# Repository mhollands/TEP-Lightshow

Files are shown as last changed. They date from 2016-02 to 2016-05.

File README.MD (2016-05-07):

This is the 2016 redesign of the Tau Epsilon Phi, Xi Chapter (MIT) light show. The aim is to have 32 individually addressable 20A wall outlets (on the ceiling). Using the DMX512 protocol, we will be able to turn on, turn off or dim any of the 32 outlets. The DMX signal will come from a PC. The main use of this is to flash the lights in accordance with the current music, via a frequency analysis of the sound, however it will likely also be used for controlling the general lighting in the room, as well as whatever we dream up.

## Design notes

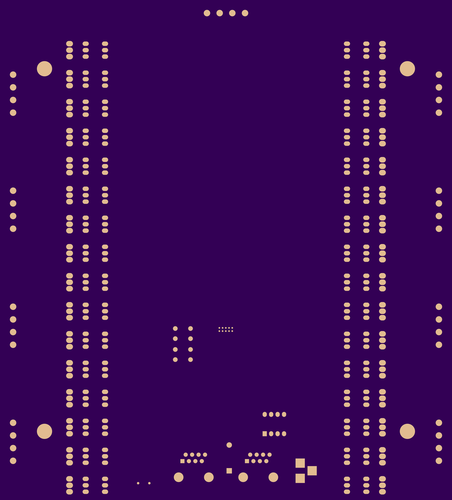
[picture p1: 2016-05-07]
Gerber/Renders/bottommask.png

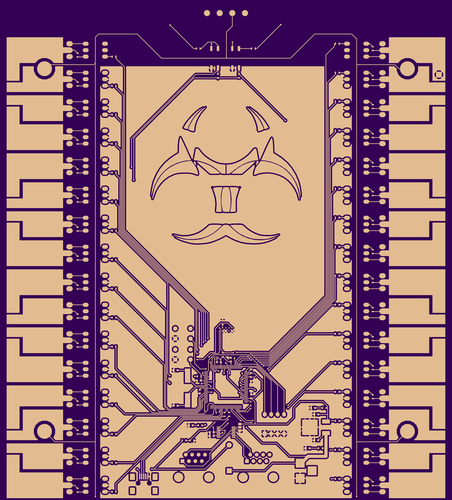
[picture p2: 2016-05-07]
Gerber/Renders/topcu.png

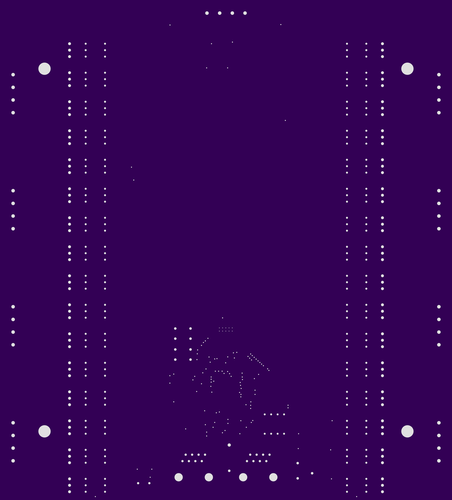
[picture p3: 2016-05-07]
Gerber/Renders/drills.png

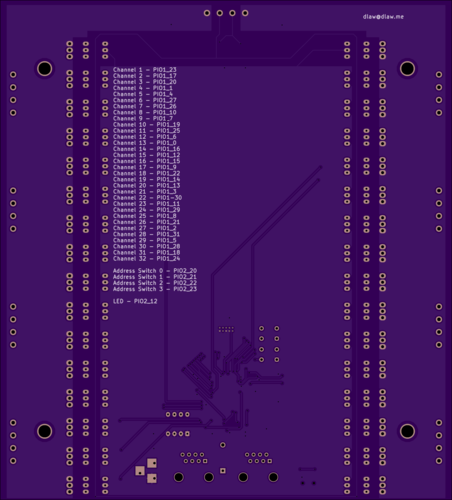
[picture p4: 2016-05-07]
Gerber/Renders/bottom.png

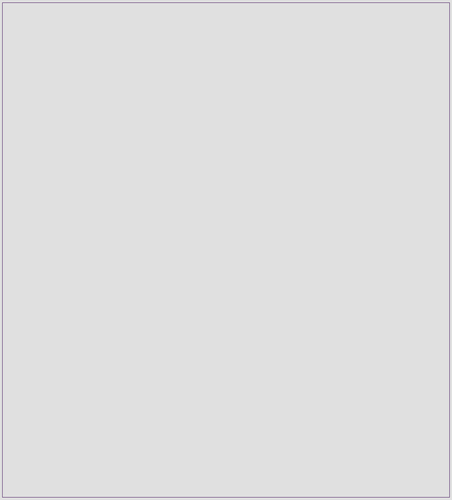
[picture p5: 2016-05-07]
Gerber/Renders/outline.png

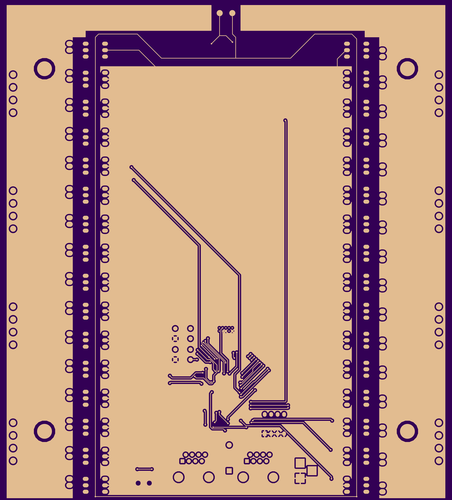
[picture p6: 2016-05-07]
Gerber/Renders/bottomcu.png

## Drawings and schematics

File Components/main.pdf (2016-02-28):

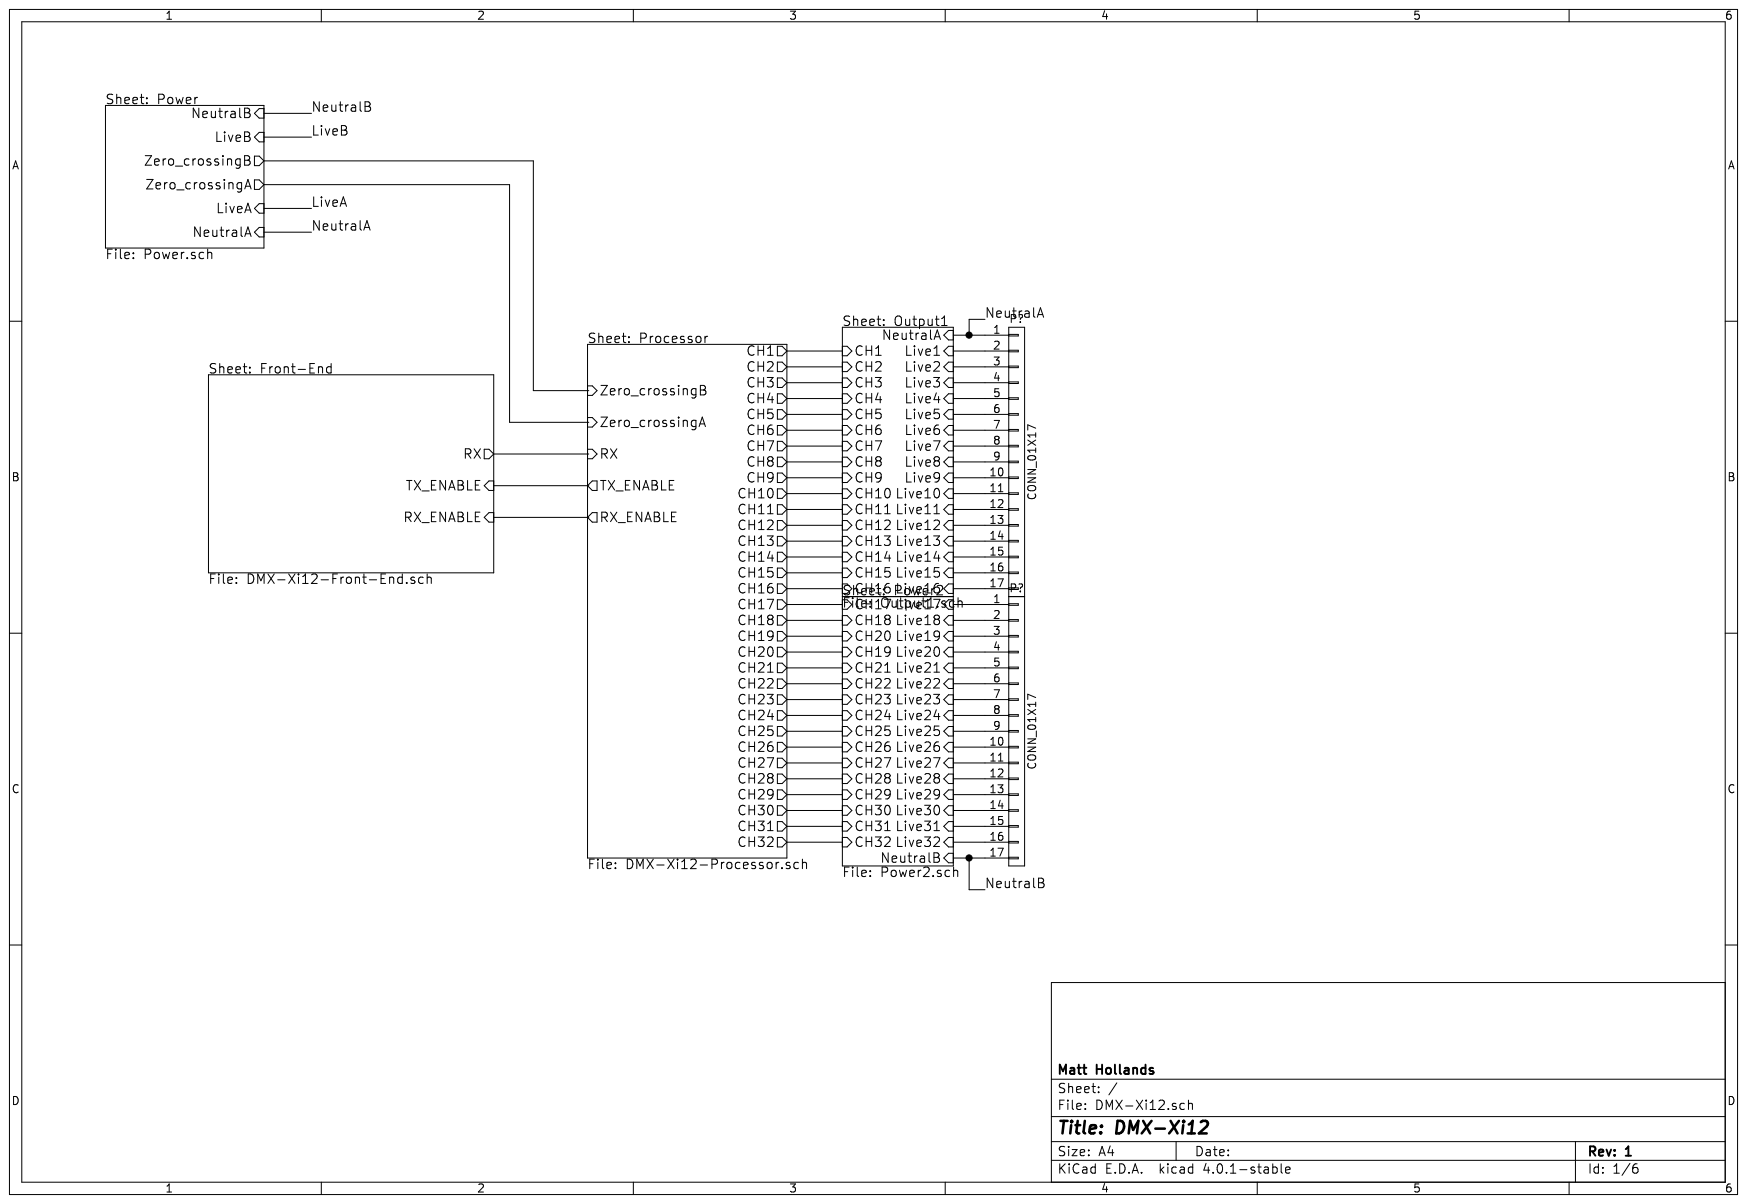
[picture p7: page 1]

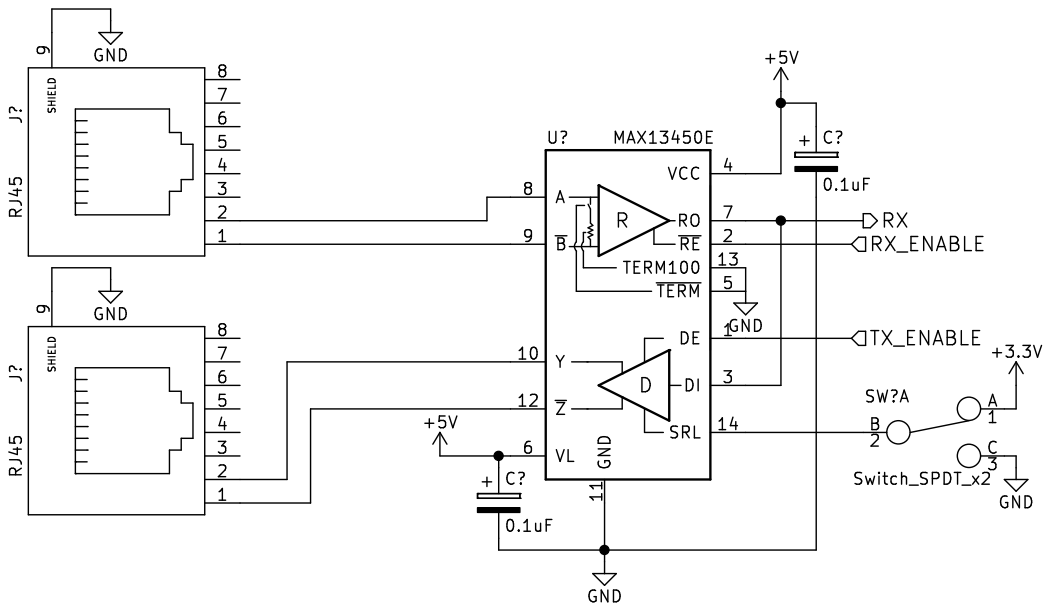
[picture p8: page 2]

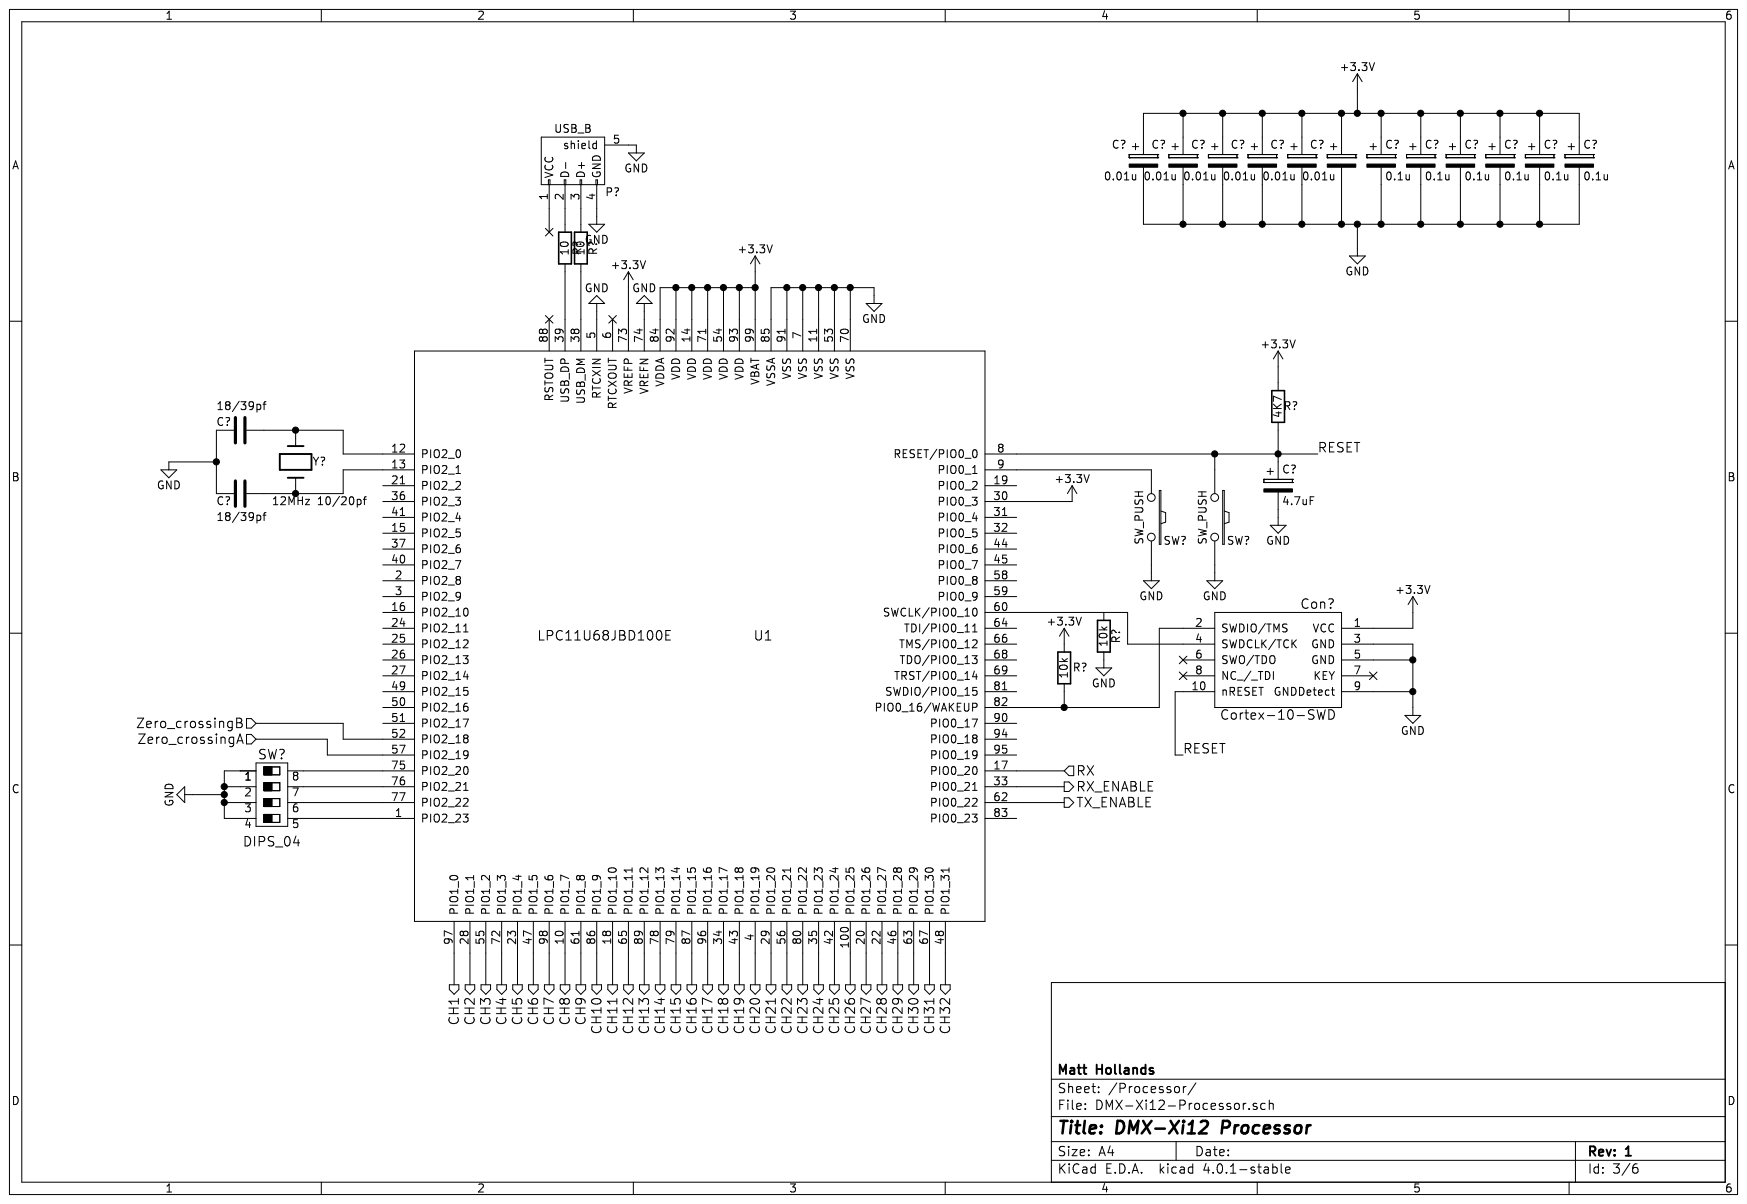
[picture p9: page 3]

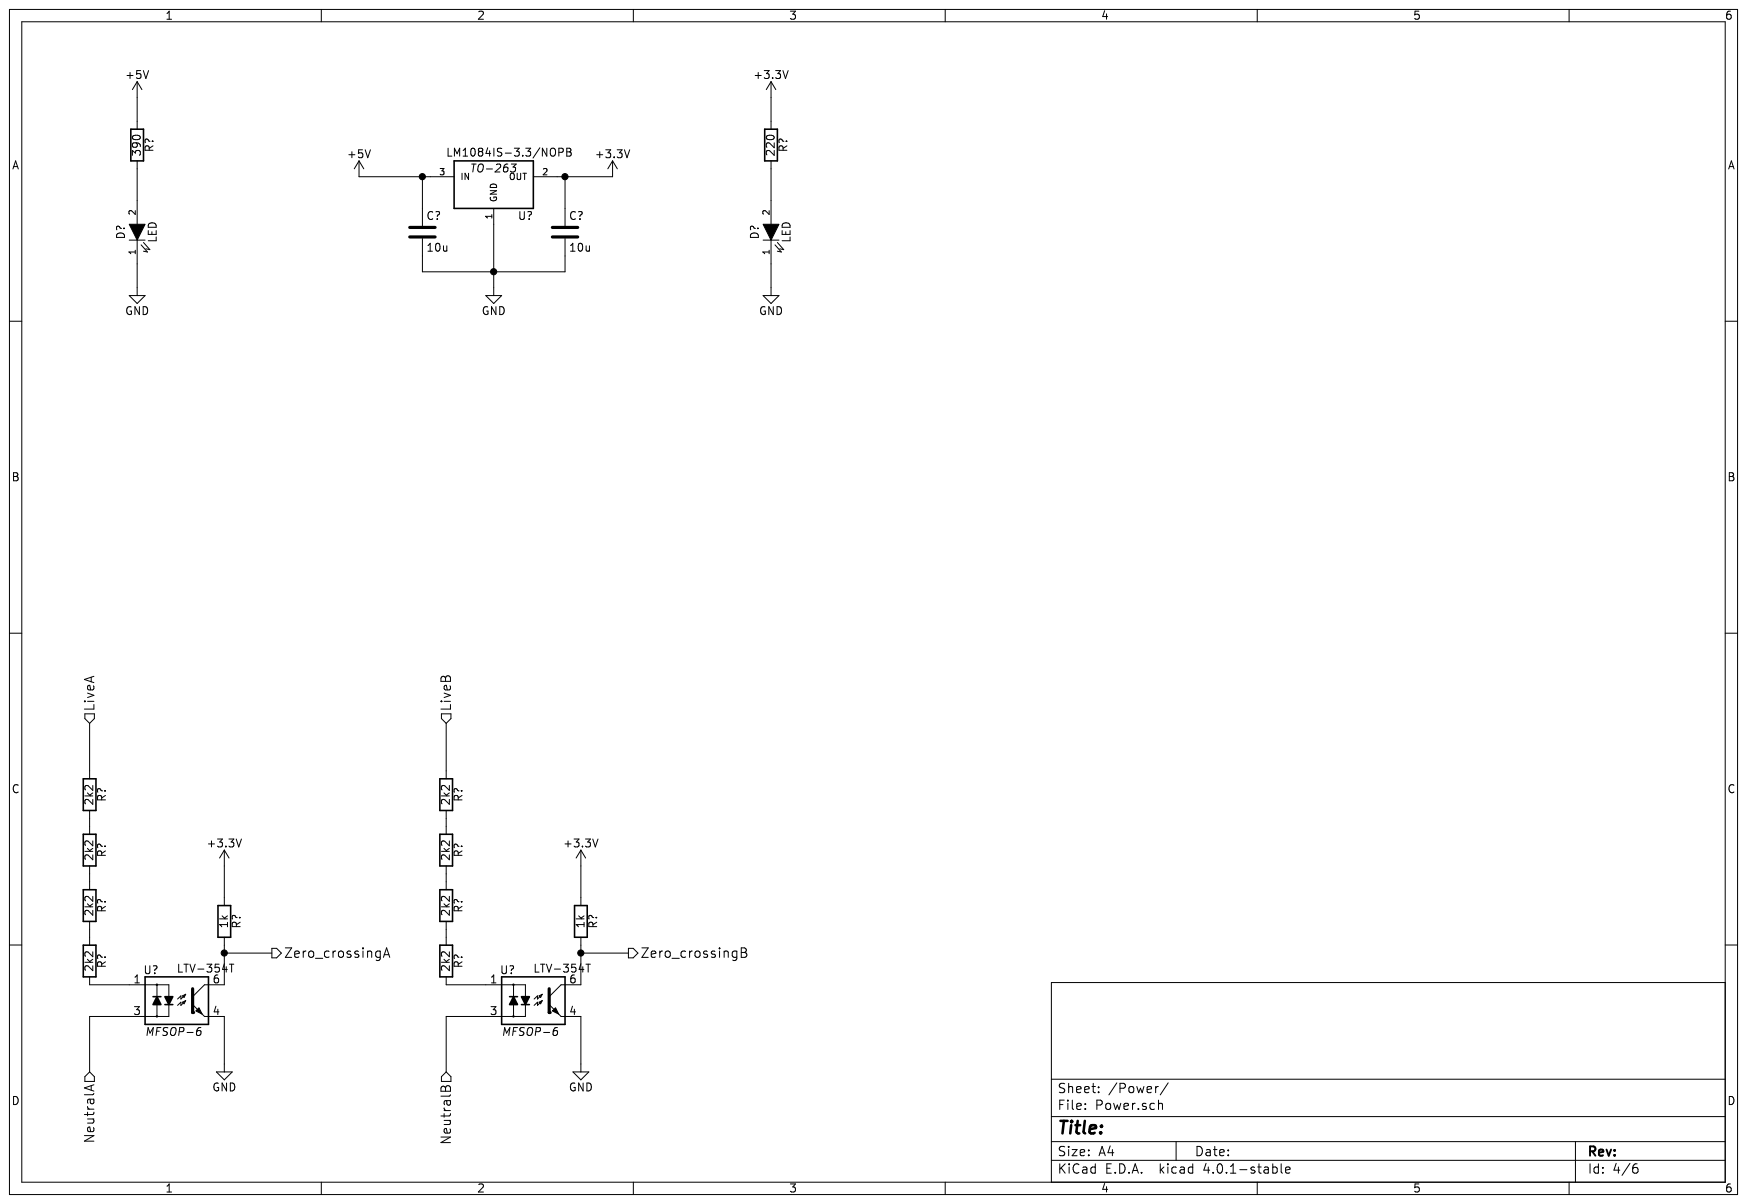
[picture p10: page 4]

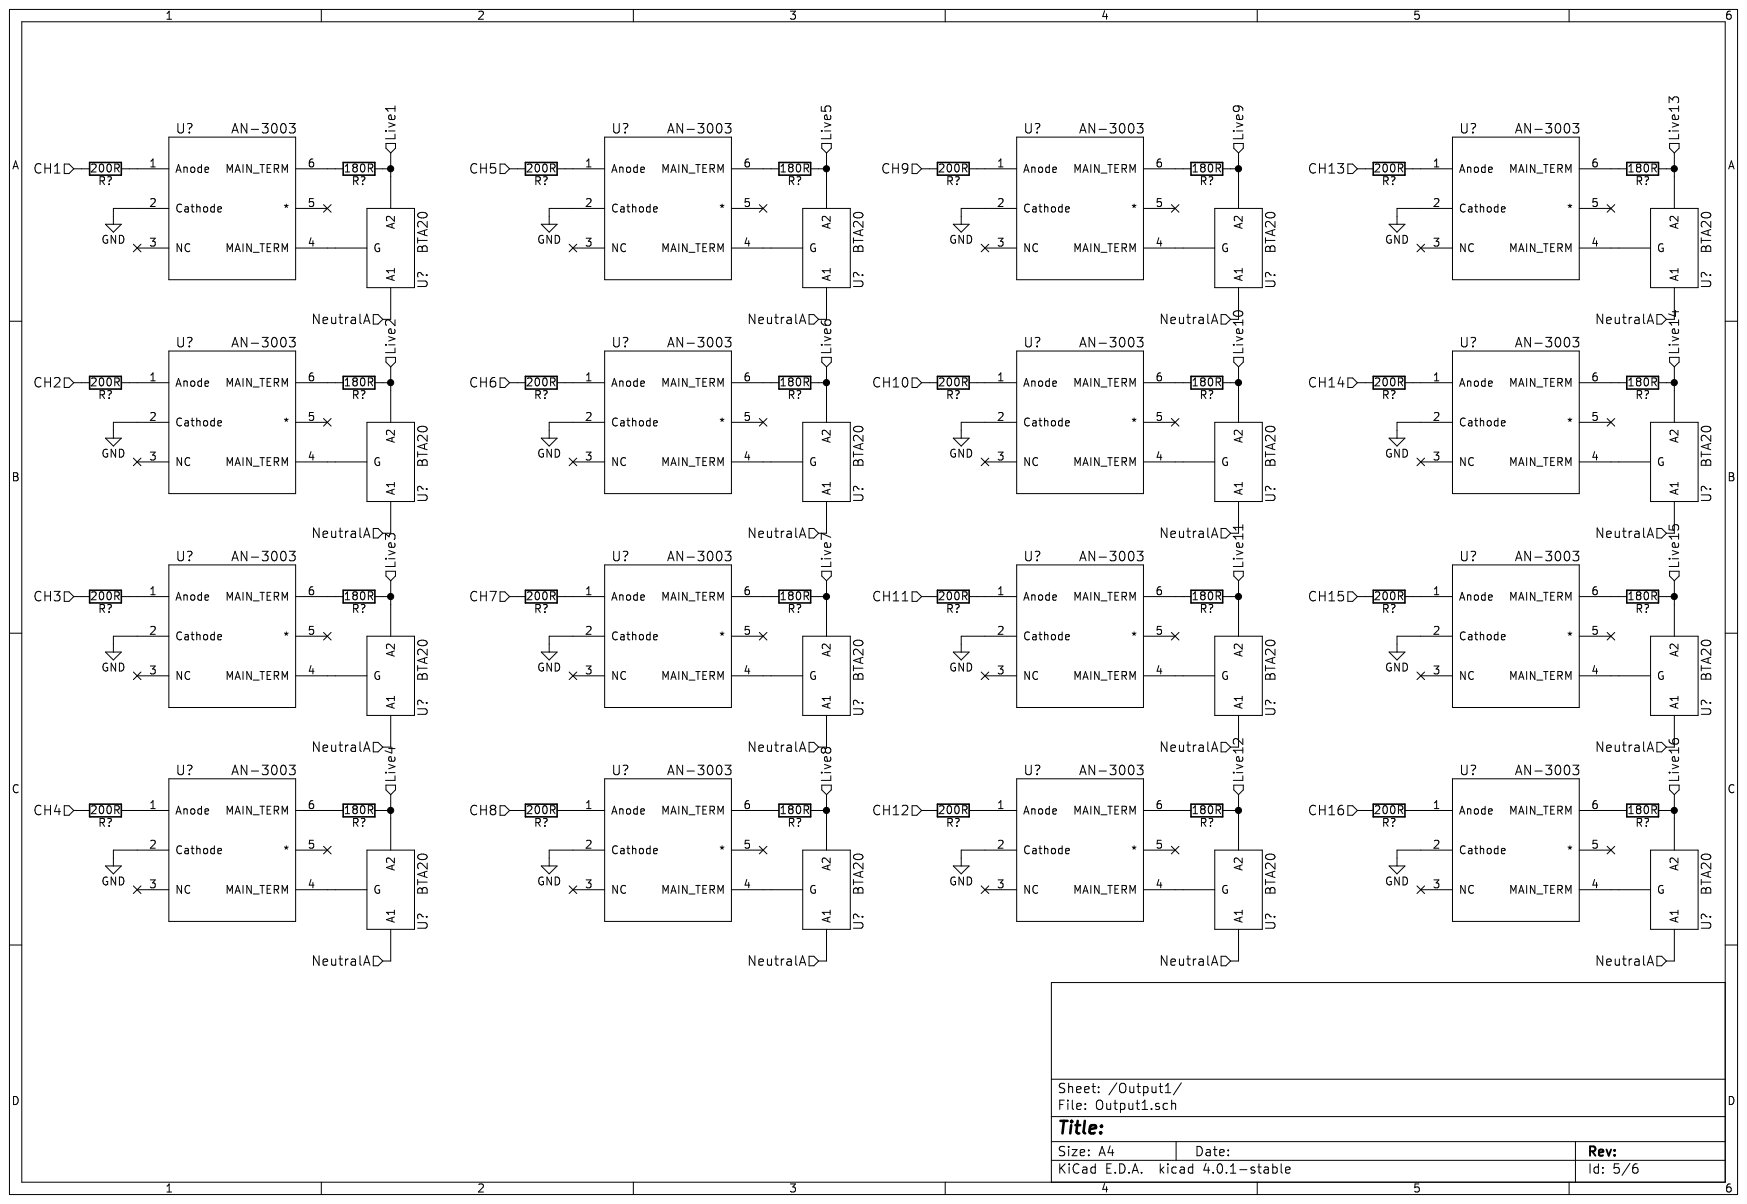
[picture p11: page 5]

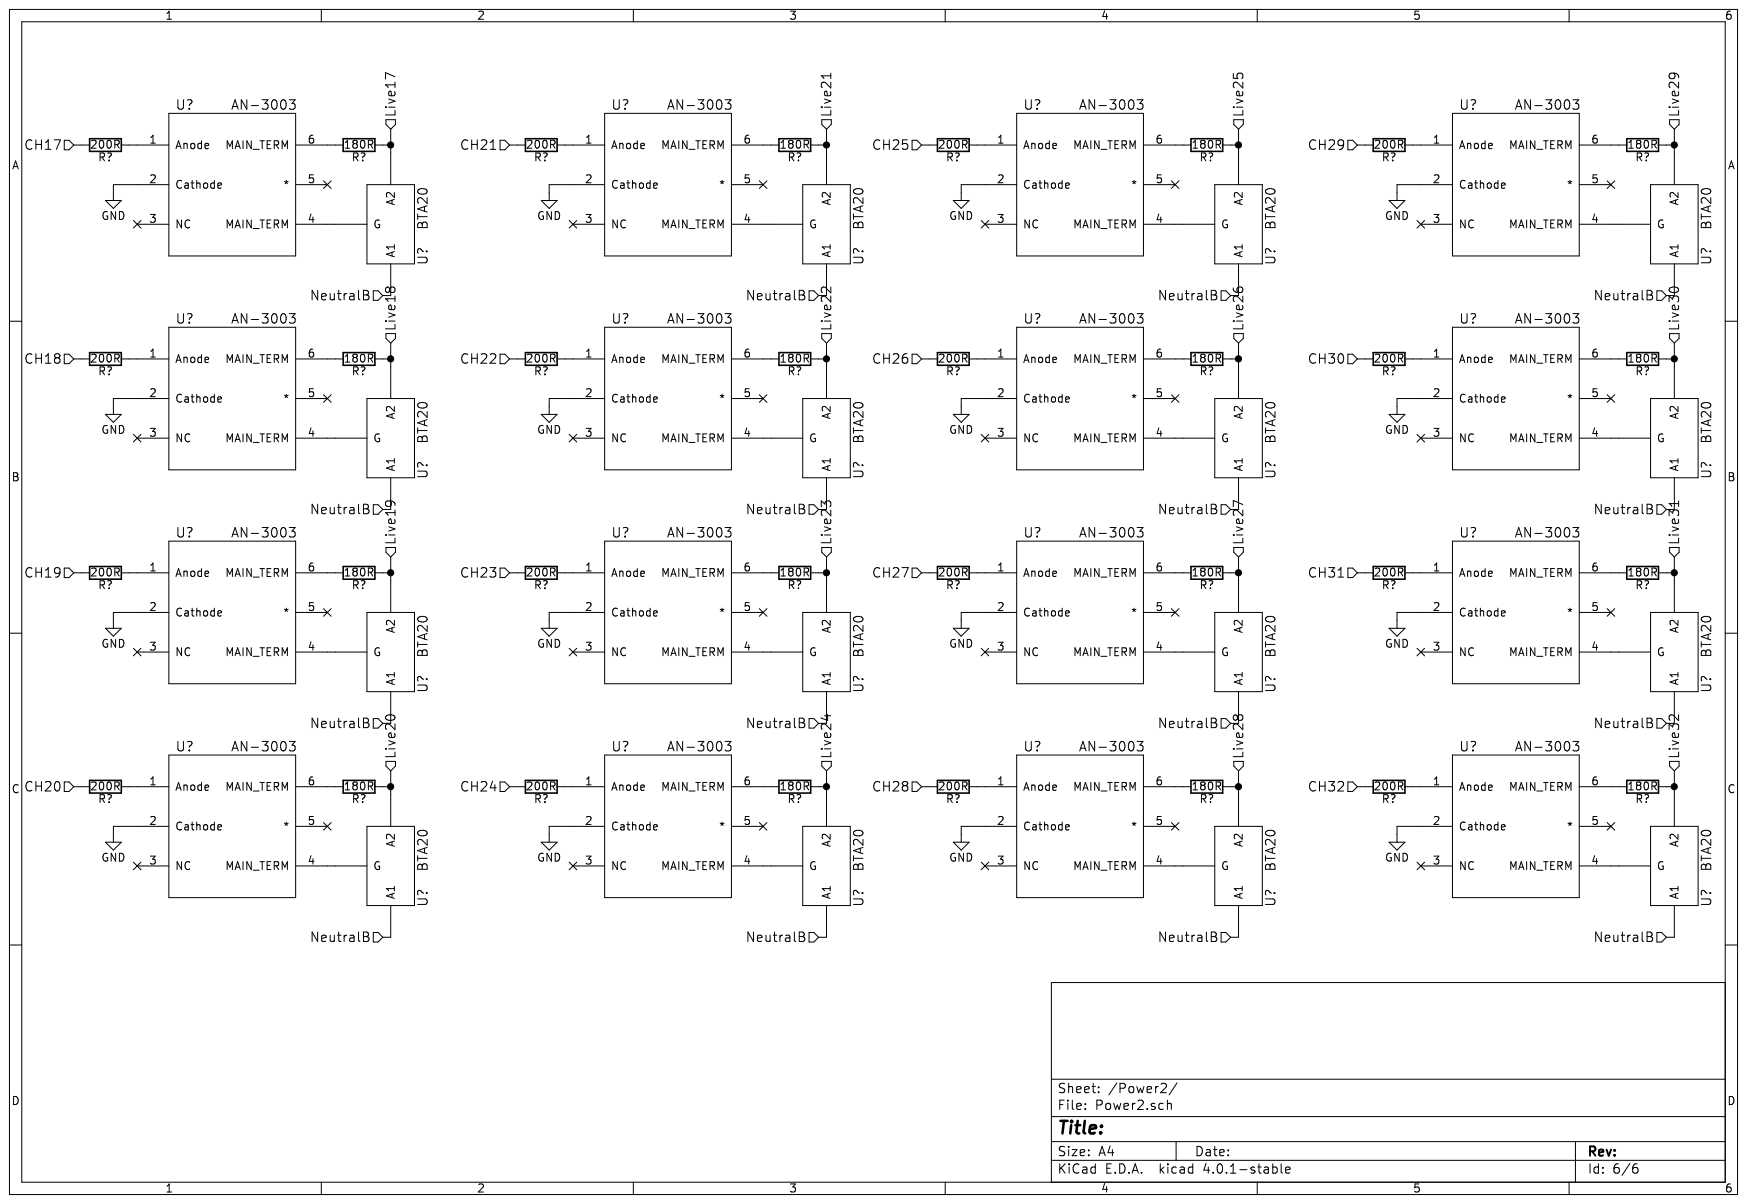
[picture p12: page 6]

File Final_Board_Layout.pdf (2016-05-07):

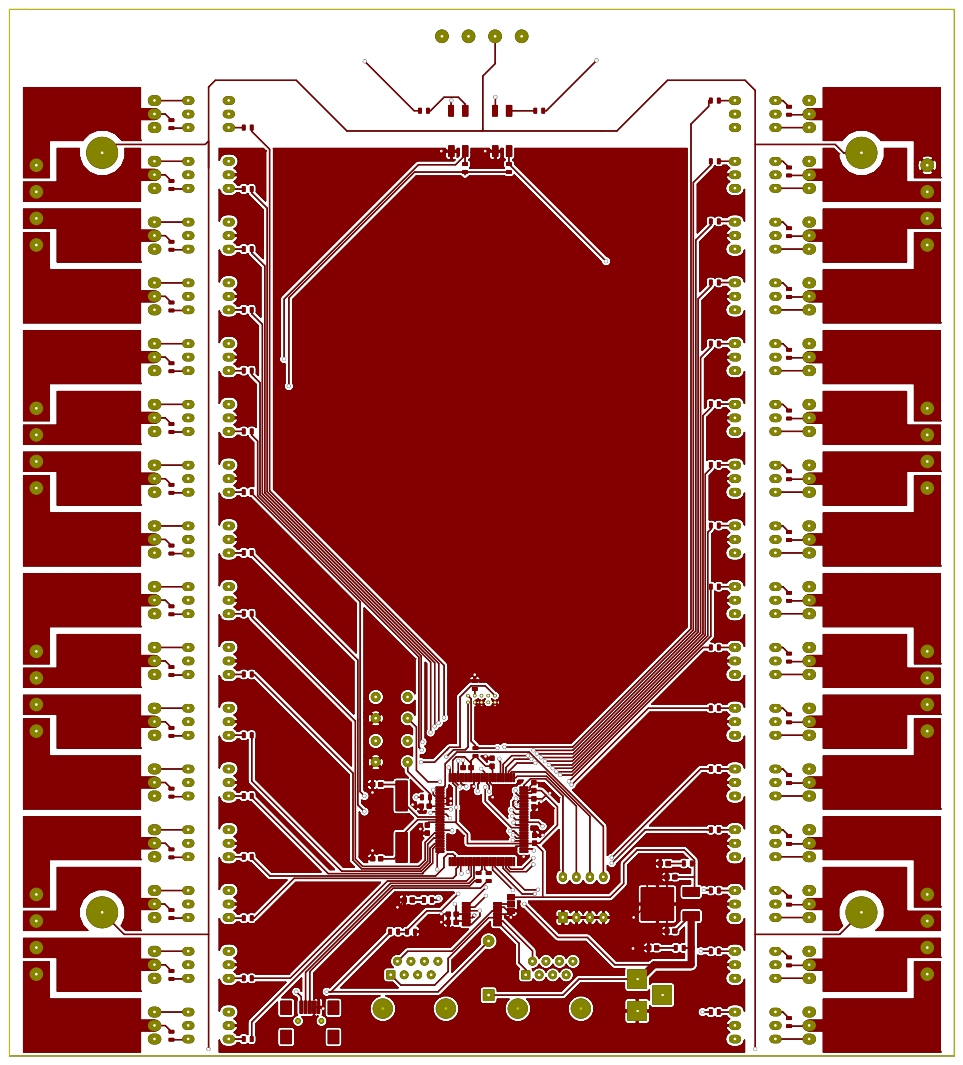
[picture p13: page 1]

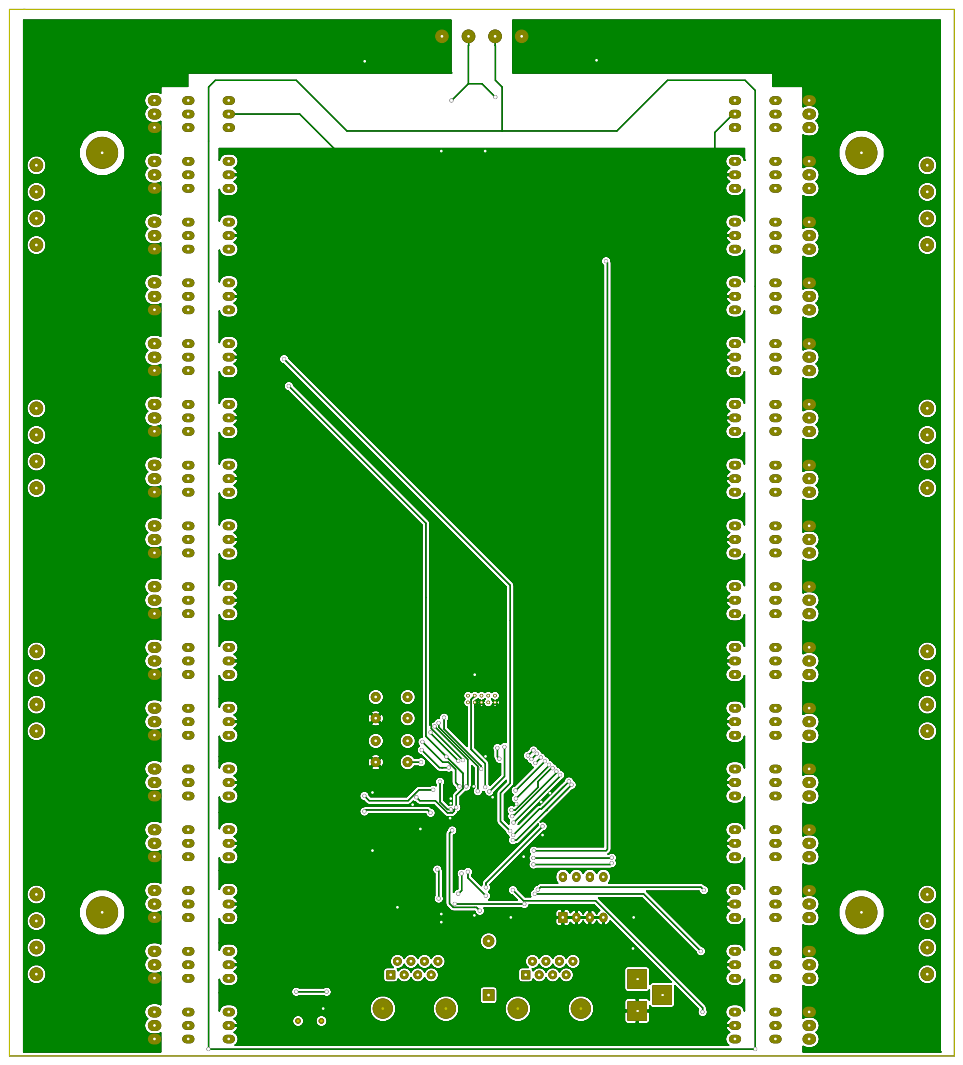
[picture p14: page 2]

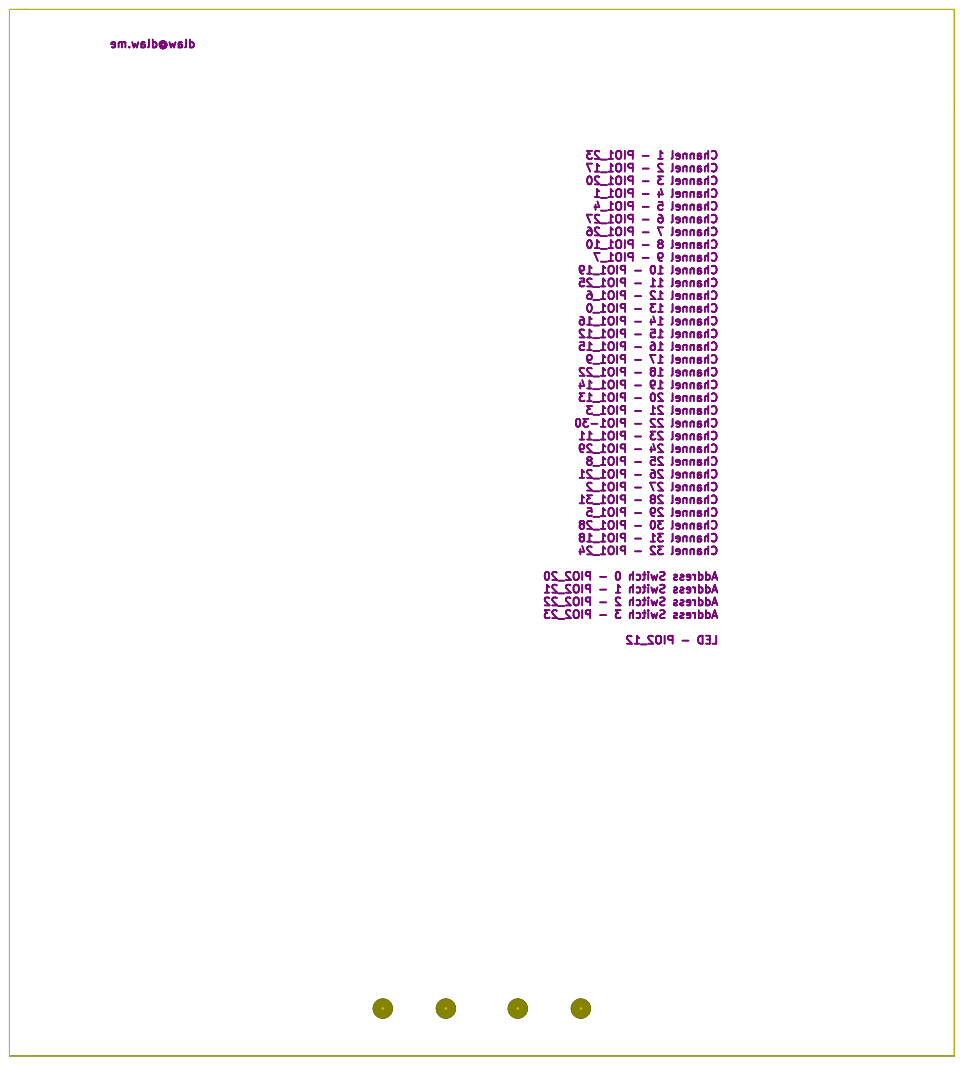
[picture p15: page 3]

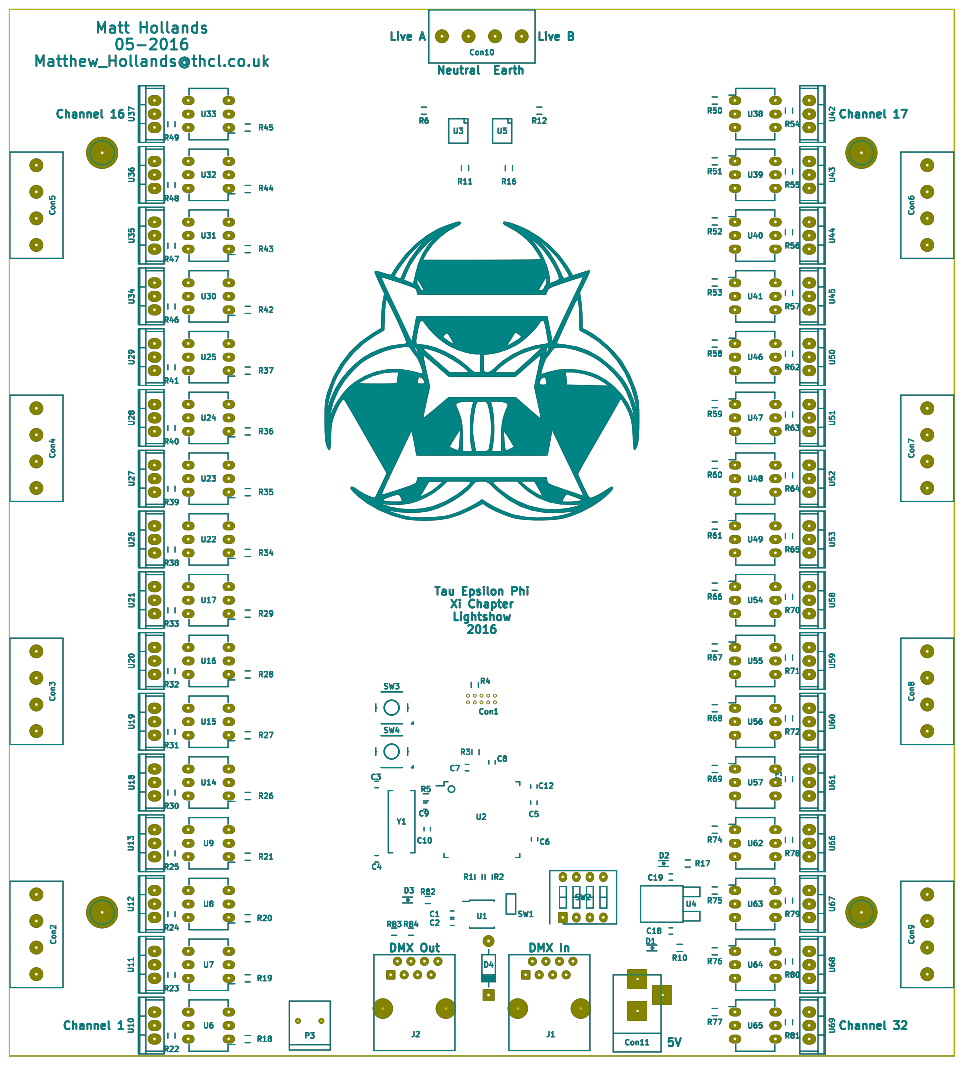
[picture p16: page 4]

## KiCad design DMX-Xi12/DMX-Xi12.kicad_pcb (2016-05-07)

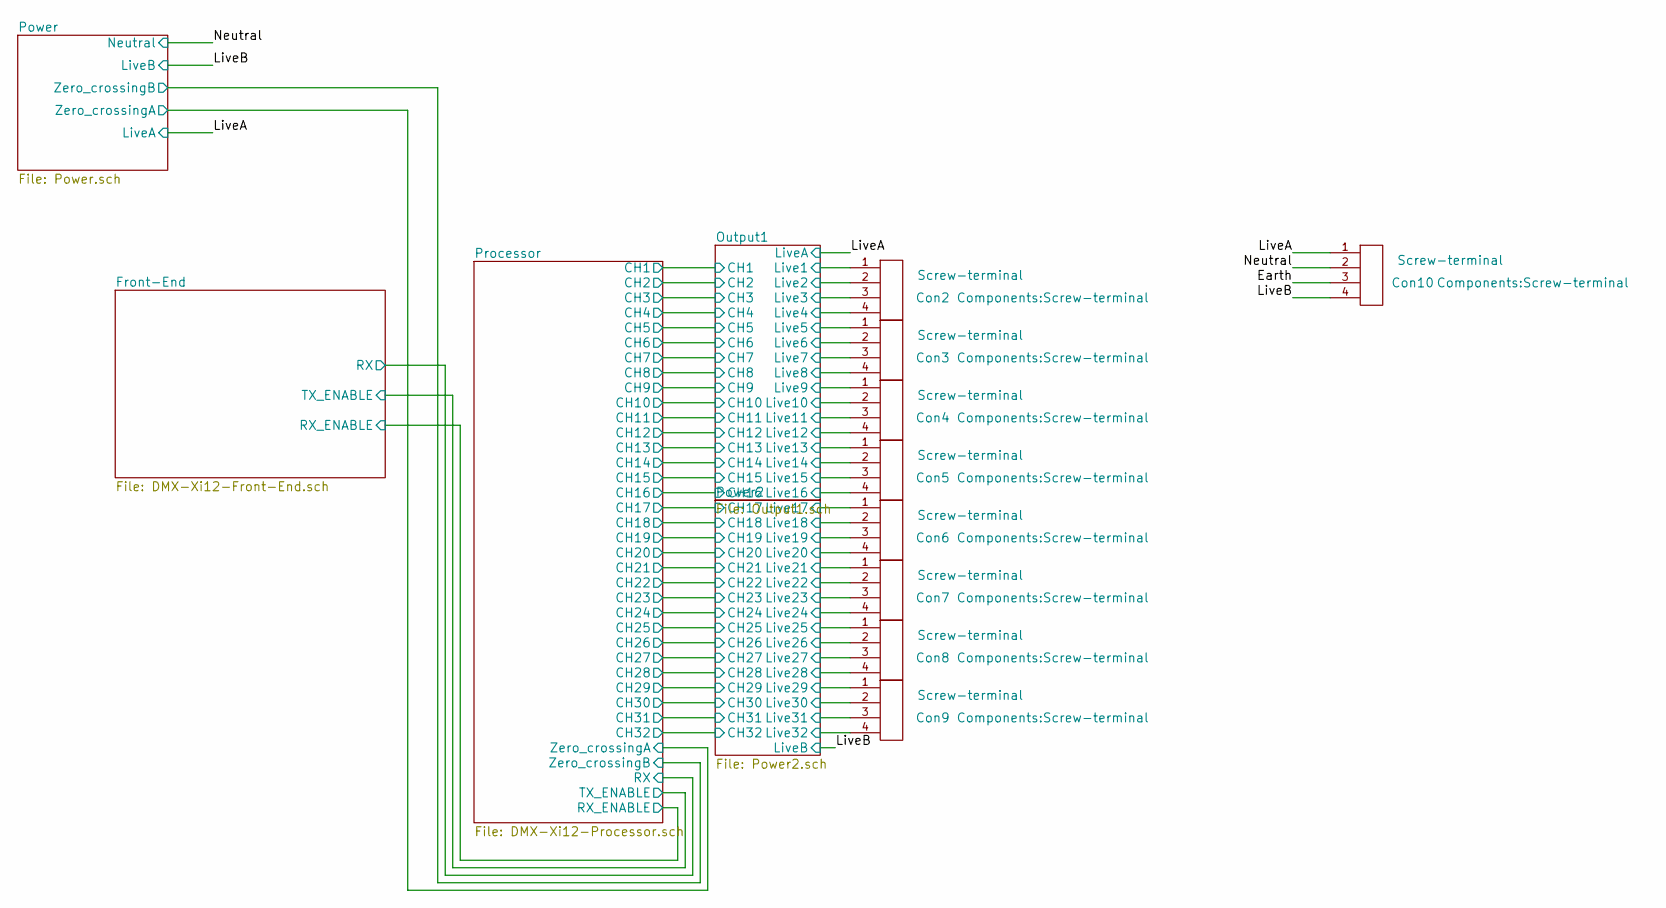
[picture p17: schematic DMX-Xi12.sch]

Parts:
Con2, Con3, Con4, Con5, Con6, Con7, Con8, Con9, Con10: Screw-terminal

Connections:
/Earth: Con10.3
/Output1/Live1: Con2.1; also elsewhere on the board
/Output1/Live2: Con2.2; also elsewhere on the board
/Output1/Live3: Con2.3; also elsewhere on the board
/Output1/Live4: Con2.4; also elsewhere on the board
/Output1/Live5: Con3.1; also elsewhere on the board
/Output1/Live6: Con3.2; also elsewhere on the board
/Output1/Live7: Con3.3; also elsewhere on the board
/Output1/Live8: Con3.4; also elsewhere on the board
/Output1/Live9: Con4.1; also elsewhere on the board
/Output1/Live10: Con4.2; also elsewhere on the board
/Output1/Live11: Con4.3; also elsewhere on the board
/Output1/Live12: Con4.4; also elsewhere on the board
/Output1/Live13: Con5.1; also elsewhere on the board
/Output1/Live14: Con5.2; also elsewhere on the board
/Output1/Live15: Con5.3; also elsewhere on the board
/Output1/Live16: Con5.4; also elsewhere on the board
/Output1/LiveA: Con10.1; also elsewhere on the board
/Power2/Live17: Con6.1; also elsewhere on the board
/Power2/Live18: Con6.2; also elsewhere on the board
/Power2/Live19: Con6.3; also elsewhere on the board
/Power2/Live20: Con6.4; also elsewhere on the board
/Power2/Live21: Con7.1; also elsewhere on the board
/Power2/Live22: Con7.2; also elsewhere on the board
/Power2/Live23: Con7.3; also elsewhere on the board
/Power2/Live24: Con7.4; also elsewhere on the board
/Power2/Live25: Con8.1; also elsewhere on the board
/Power2/Live26: Con8.2; also elsewhere on the board
/Power2/Live27: Con8.3; also elsewhere on the board
/Power2/Live28: Con8.4; also elsewhere on the board
/Power2/Live29: Con9.1; also elsewhere on the board
/Power2/Live30: Con9.2; also elsewhere on the board
/Power2/Live31: Con9.3; also elsewhere on the board
/Power2/Live32: Con9.4; also elsewhere on the board
/Power/LiveB: Con10.4; also elsewhere on the board
/Power/Neutral: Con10.2; also elsewhere on the board

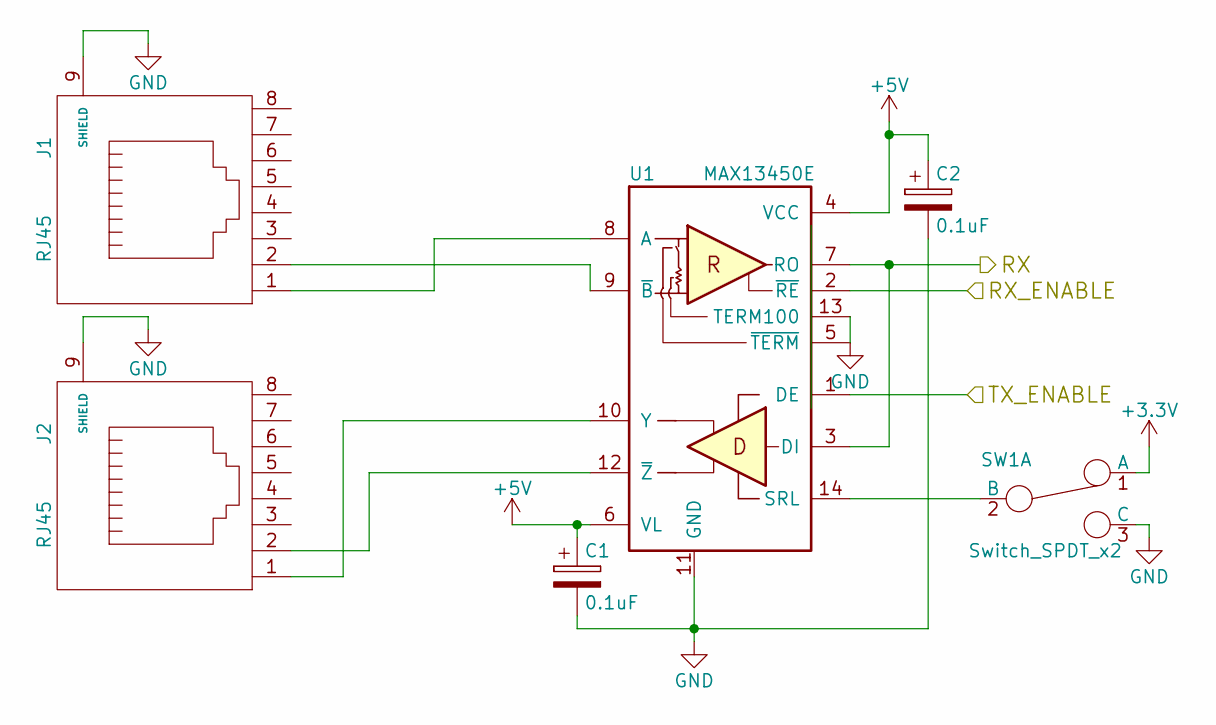
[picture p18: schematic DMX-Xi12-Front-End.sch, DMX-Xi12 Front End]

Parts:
C1, C2: 0.1uF; C_0603
J1, J2: RJ45; RJ45_8
SW1: Switch_SPDT_x2; GS3
U1: MAX13450E; TSSOP-14_4.4x5mm_Pitch0.65mm

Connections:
+5V: C1.1, C2.1, U1.4 (VCC), U1.6 (VL); also elsewhere on the board
/Front-End/RX: U1.3 (DI), U1.7 (RO); also elsewhere on the board
/Front-End/RX_ENABLE: U1.2 (~RE); also elsewhere on the board
/Front-End/TX_ENABLE: U1.1 (DE); also elsewhere on the board
unnamed: J1.1, U1.8 (A)
unnamed: J1.2, U1.9 (~B)
unnamed: J2.1, U1.10 (Y)
unnamed: J2.2, U1.12 (~Z)
unnamed: SW1.2 (B), U1.14 (SRL)

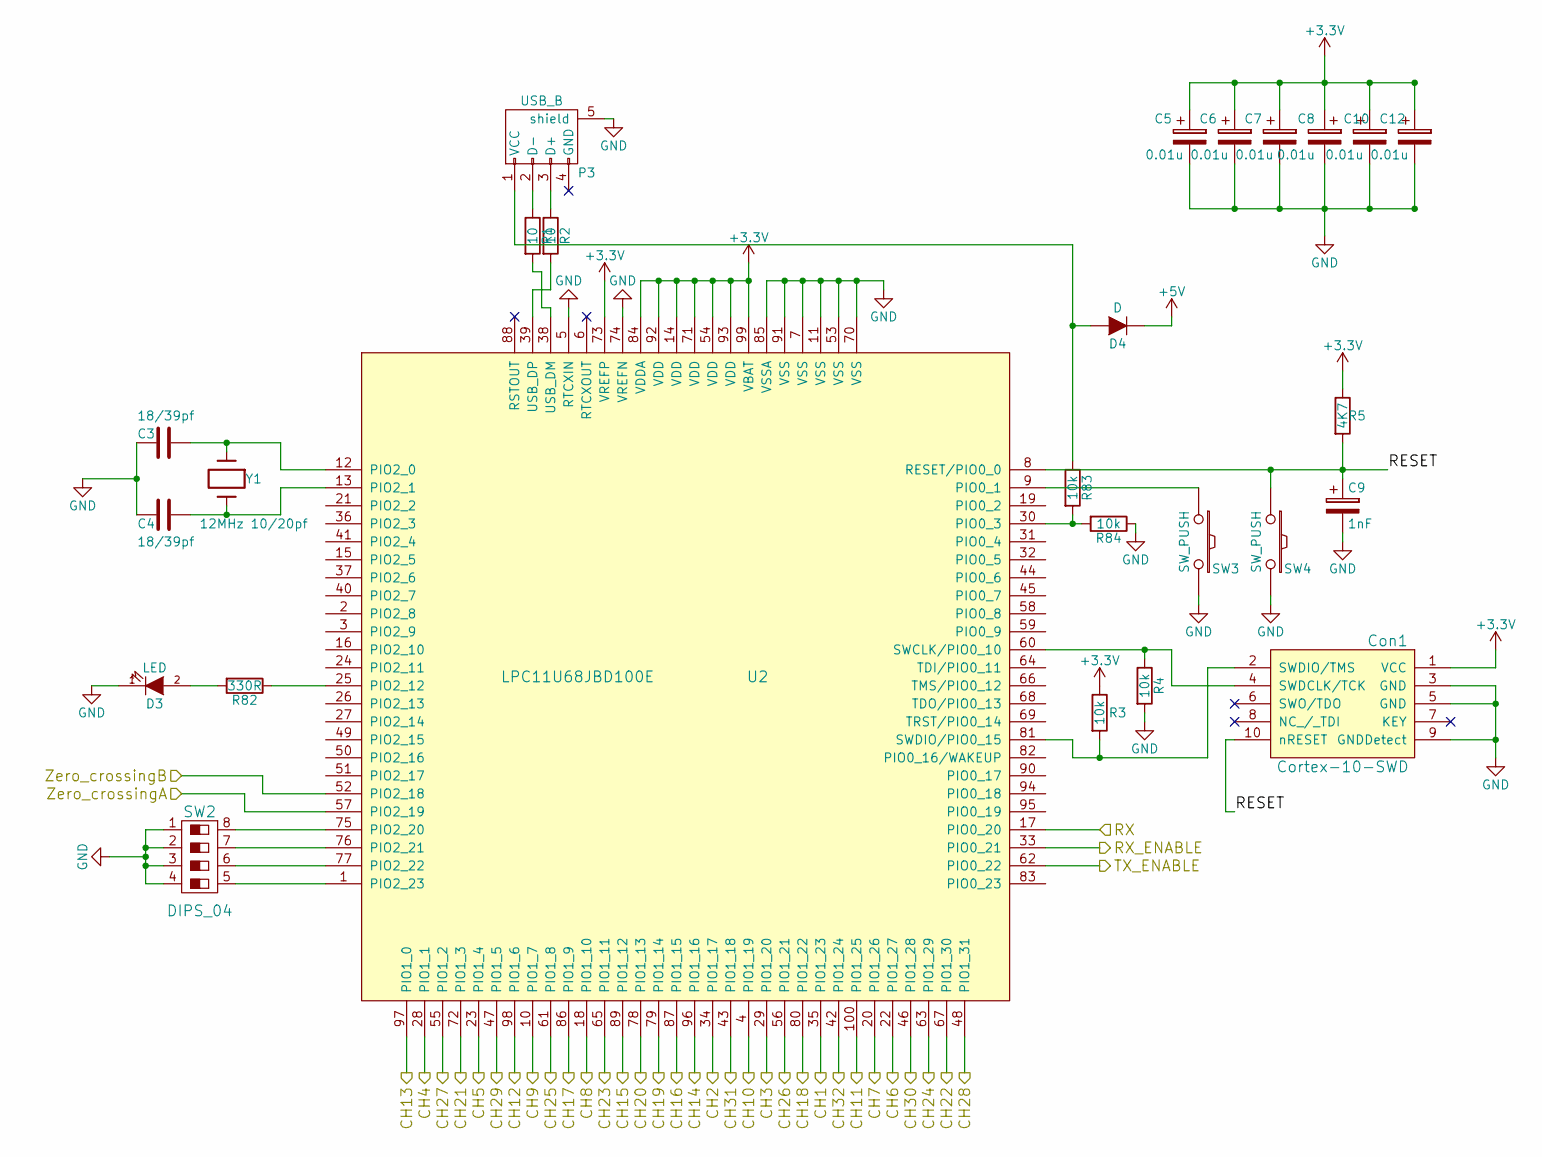
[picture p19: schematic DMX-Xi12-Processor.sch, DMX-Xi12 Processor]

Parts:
C3, C4: 18/39pf; C_0603
C5, C6, C7, C8, C10, C12: 0.01u; C_0603
C9: 1nF; C_0603
Con1: Cortex-10-SWD
D3: LED; LED_0603
D4: D; Diode_DO-41_SOD81_Horizontal_RM10
P3: USB_B; USB_Mini-B
R1, R2: 10; R_0603
R3, R4, R83, R84: 10k; R_0603
R5: 4K7; R_0603
R82: 330R; R_0603
SW2: DIPS_04; SW_DIP_x4_Slide
SW3, SW4: SW_PUSH; SW_TH_Tactile_Omron_B3F-10xx
U2: LPC11U68JBD100E; LQFP-100_14x14mm_Pitch0.5mm
Y1: 12MHz 10/20pf; Crystal_HC49-SD_SMD

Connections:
+5V: D4.1 (K); also elsewhere on the board
/Front-End/RX: U2.17 (PIO0_20); also elsewhere on the board
/Front-End/RX_ENABLE: U2.33 (PIO0_21); also elsewhere on the board
/Front-End/TX_ENABLE: U2.62 (PIO0_22); also elsewhere on the board
/Output1/CH1: U2.35 (PIO1_23); also elsewhere on the board
/Output1/CH2: U2.34 (PIO1_17); also elsewhere on the board
/Output1/CH3: U2.29 (PIO1_20); also elsewhere on the board
/Output1/CH4: U2.28 (PIO1_1); also elsewhere on the board
/Output1/CH5: U2.23 (PIO1_4); also elsewhere on the board
/Output1/CH6: U2.22 (PIO1_27); also elsewhere on the board
/Output1/CH7: U2.20 (PIO1_26); also elsewhere on the board
/Output1/CH8: U2.18 (PIO1_10); also elsewhere on the board
/Output1/CH9: U2.10 (PIO1_7); also elsewhere on the board
/Output1/CH10: U2.4 (PIO1_19); also elsewhere on the board
/Output1/CH11: U2.100 (PIO1_25); also elsewhere on the board
/Output1/CH12: U2.98 (PIO1_6); also elsewhere on the board
/Output1/CH13: U2.97 (PIO1_0); also elsewhere on the board
/Output1/CH14: U2.96 (PIO1_16); also elsewhere on the board
/Output1/CH15: U2.89 (PIO1_12); also elsewhere on the board
/Output1/CH16: U2.87 (PIO1_15); also elsewhere on the board
/Power2/CH17: U2.86 (PIO1_9); also elsewhere on the board
/Power2/CH18: U2.80 (PIO1_22); also elsewhere on the board
/Power2/CH19: U2.79 (PIO1_14); also elsewhere on the board
/Power2/CH20: U2.78 (PIO1_13); also elsewhere on the board
/Power2/CH21: U2.72 (PIO1_3); also elsewhere on the board
/Power2/CH22: U2.67 (PIO1_30); also elsewhere on the board
/Power2/CH23: U2.65 (PIO1_11); also elsewhere on the board
/Power2/CH24: U2.63 (PIO1_29); also elsewhere on the board
/Power2/CH25: U2.61 (PIO1_8); also elsewhere on the board
/Power2/CH26: U2.56 (PIO1_21); also elsewhere on the board
/Power2/CH27: U2.55 (PIO1_2); also elsewhere on the board
/Power2/CH28: U2.48 (PIO1_31); also elsewhere on the board
/Power2/CH29: U2.47 (PIO1_5); also elsewhere on the board
/Power2/CH30: U2.46 (PIO1_28); also elsewhere on the board
/Power2/CH31: U2.43 (PIO1_18); also elsewhere on the board
/Power2/CH32: U2.42 (PIO1_24); also elsewhere on the board
/Power/Zero_crossingA: U2.57 (PIO2_19); also elsewhere on the board
/Power/Zero_crossingB: U2.52 (PIO2_18); also elsewhere on the board
/Processor/RESET: C9.1, Con1.10 (nRESET), R5.2, SW4.1, U2.8 (RESET/PIO0_0)
unnamed: C3.1, U2.12 (PIO2_0), Y1.1
unnamed: C4.1, U2.13 (PIO2_1), Y1.2
unnamed: Con1.2 (SWDIO/TMS), R3.2, U2.81 (SWDIO/PIO0_15)
unnamed: Con1.4 (SWDCLK/TCK), R4.1, U2.60 (SWCLK/PIO0_10)
unnamed: D3.2 (A), R82.2
unnamed: D4.2 (A), P3.1 (VCC), R83.1
unnamed: P3.2 (D-), R1.1
unnamed: P3.3 (D+), R2.1
unnamed: R1.2, U2.38 (USB_DM)
unnamed: R2.2, U2.39 (USB_DP)
unnamed: R82.1, U2.25 (PIO2_12)
unnamed: R83.2, R84.2, U2.30 (PIO0_3)
unnamed: SW2.5, U2.1 (PIO2_23)
unnamed: SW2.6, U2.77 (PIO2_22)
unnamed: SW2.7, U2.76 (PIO2_21)
unnamed: SW2.8, U2.75 (PIO2_20)
unnamed: SW3.1, U2.9 (PIO0_1)

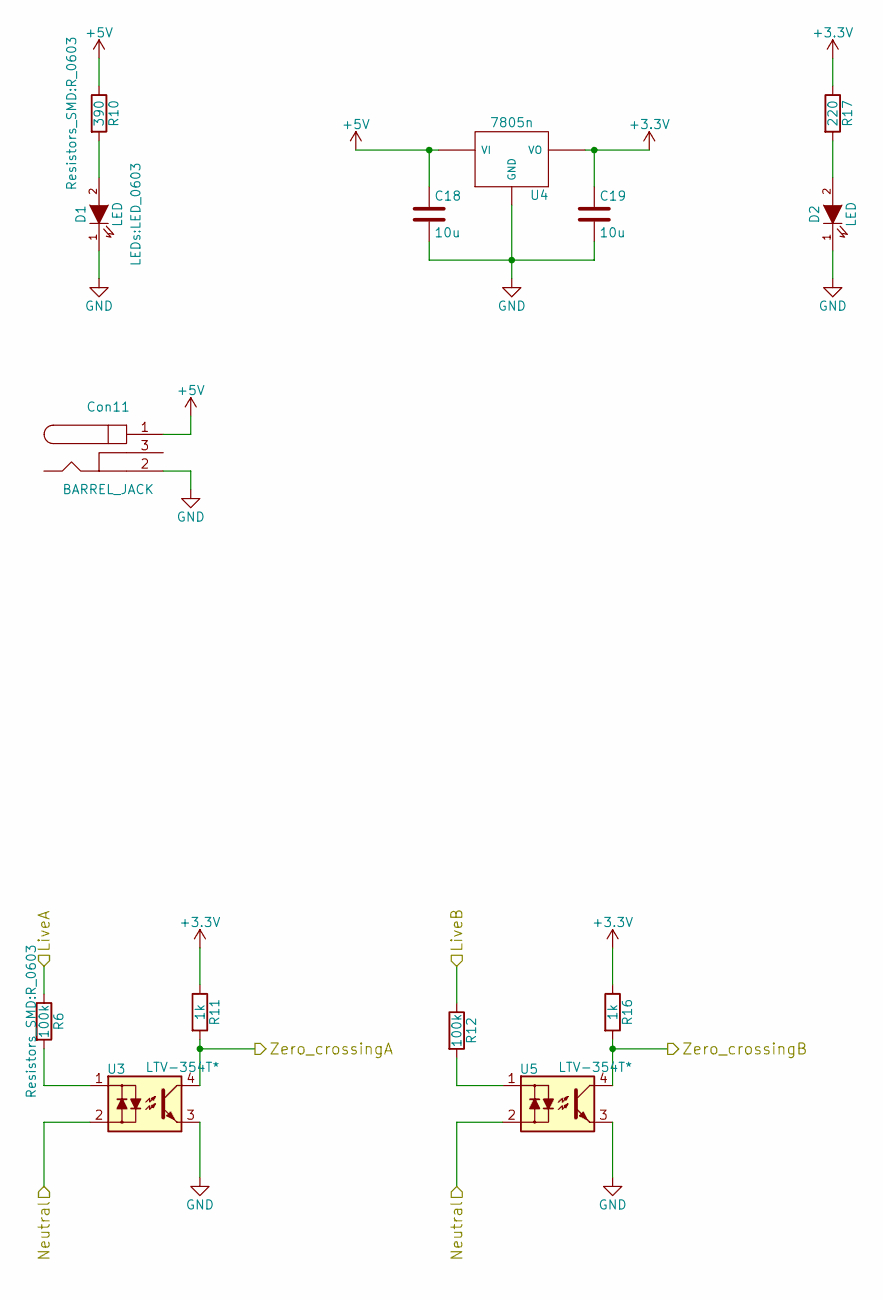
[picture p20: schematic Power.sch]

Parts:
C18, C19: 10u; C_0603
Con11: BARREL_JACK
D1, D2: LED; LED_0603
R6, R12: 100k; R_0603
R10: 390; R_0603
R11, R16: 1k; R_0603
R17: 220; R_0603
U3, U5: LTV-354T*
U4: 7805n

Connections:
+5V: C18.1, Con11.1, R10.1, U4.1 (VI); also elsewhere on the board
/Output1/LiveA: R6.1; also elsewhere on the board
/Power/LiveB: R12.1; also elsewhere on the board
/Power/Neutral: U3.2, U5.2; also elsewhere on the board
/Power/Zero_crossingA: R11.2, U3.4; also elsewhere on the board
/Power/Zero_crossingB: R16.2, U5.4; also elsewhere on the board
unnamed: D1.2 (A), R10.2
unnamed: D2.2 (A), R17.2
unnamed: R6.2, U3.1
unnamed: R12.2, U5.1

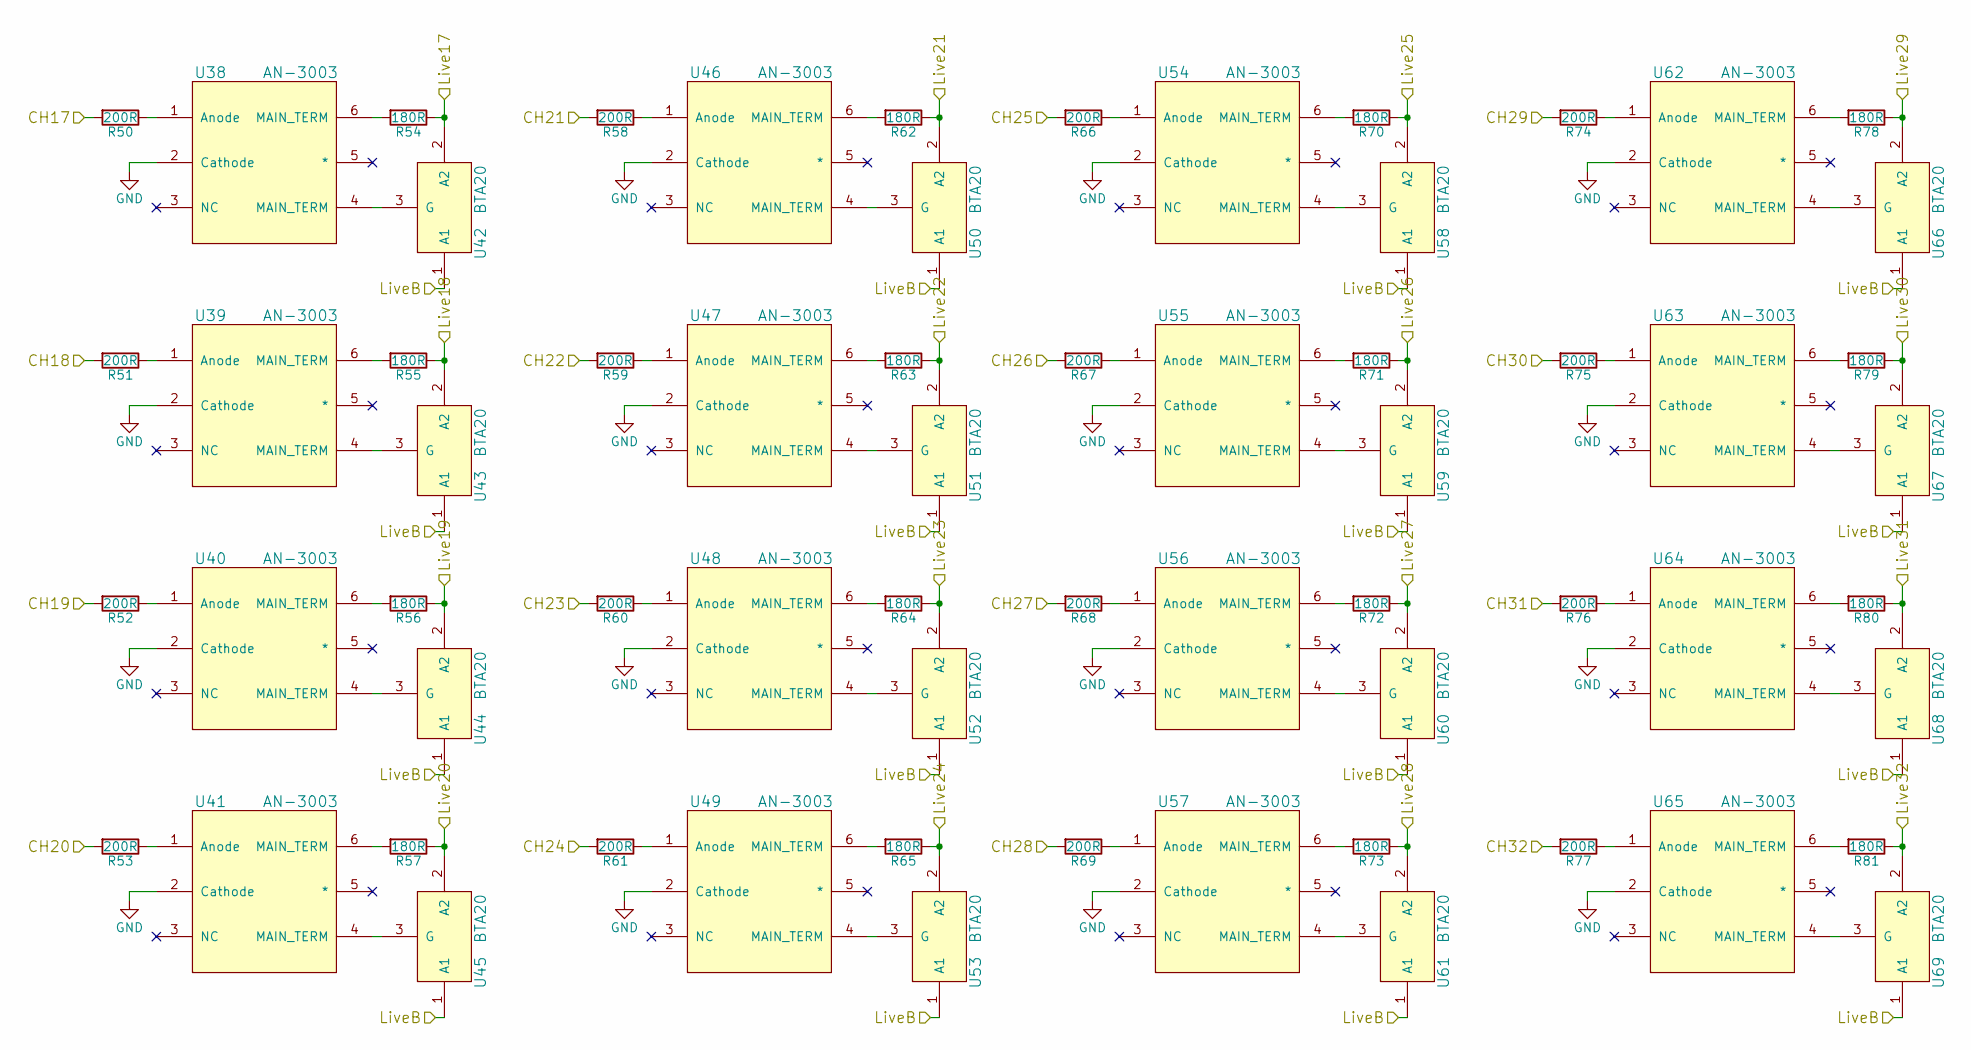
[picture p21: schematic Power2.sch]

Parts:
R50, R51, R52, R53, R58, R59, R60, R61, R66, R67, R68, R69, R74, R75, R76, R77: 200R; R_0603
R54, R55, R56, R57, R62, R63, R64, R65, R70, R71, R72, R73, R78, R79, R80, R81: 180R; R_0603
U38, U39, U40, U41, U46, U47, U48, U49, U54, U55, U56, U57, U62, U63, U64, U65: AN-3003; DIP-6_W7.62mm_LongPads
U42, U43, U44, U45, U50, U51, U52, U53, U58, U59, U60, U61, U66, U67, U68, U69: BTA20; TO-220

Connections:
/Power2/CH17: R50.2; also elsewhere on the board
/Power2/CH18: R51.2; also elsewhere on the board
/Power2/CH19: R52.2; also elsewhere on the board
/Power2/CH20: R53.2; also elsewhere on the board
/Power2/CH21: R58.2; also elsewhere on the board
/Power2/CH22: R59.2; also elsewhere on the board
/Power2/CH23: R60.2; also elsewhere on the board
/Power2/CH24: R61.2; also elsewhere on the board
/Power2/CH25: R66.2; also elsewhere on the board
/Power2/CH26: R67.2; also elsewhere on the board
/Power2/CH27: R68.2; also elsewhere on the board
/Power2/CH28: R69.2; also elsewhere on the board
/Power2/CH29: R74.2; also elsewhere on the board
/Power2/CH30: R75.2; also elsewhere on the board
/Power2/CH31: R76.2; also elsewhere on the board
/Power2/CH32: R77.2; also elsewhere on the board
/Power2/Live17: R54.1, U42.2 (A2); also elsewhere on the board
/Power2/Live18: R55.1, U43.2 (A2); also elsewhere on the board
/Power2/Live19: R56.1, U44.2 (A2); also elsewhere on the board
/Power2/Live20: R57.1, U45.2 (A2); also elsewhere on the board
/Power2/Live21: R62.1, U50.2 (A2); also elsewhere on the board
/Power2/Live22: R63.1, U51.2 (A2); also elsewhere on the board
/Power2/Live23: R64.1, U52.2 (A2); also elsewhere on the board
/Power2/Live24: R65.1, U53.2 (A2); also elsewhere on the board
/Power2/Live25: R70.1, U58.2 (A2); also elsewhere on the board
/Power2/Live26: R71.1, U59.2 (A2); also elsewhere on the board
/Power2/Live27: R72.1, U60.2 (A2); also elsewhere on the board
/Power2/Live28: R73.1, U61.2 (A2); also elsewhere on the board
/Power2/Live29: R78.1, U66.2 (A2); also elsewhere on the board
/Power2/Live30: R79.1, U67.2 (A2); also elsewhere on the board
/Power2/Live31: R80.1, U68.2 (A2); also elsewhere on the board
/Power2/Live32: R81.1, U69.2 (A2); also elsewhere on the board
/Power/LiveB: U42.1 (A1), U43.1 (A1), U44.1 (A1), U45.1 (A1), U50.1 (A1), U51.1 (A1), U52.1 (A1), U53.1 (A1), U58.1 (A1), U59.1 (A1), U60.1 (A1), U61.1 (A1), U66.1 (A1), U67.1 (A1), U68.1 (A1), U69.1 (A1); also elsewhere on the board
unnamed: R50.1, U38.1 (Anode)
unnamed: R51.1, U39.1 (Anode)
unnamed: R52.1, U40.1 (Anode)
unnamed: R53.1, U41.1 (Anode)
unnamed: R54.2, U38.6 (MAIN_TERM)
unnamed: R55.2, U39.6 (MAIN_TERM)
unnamed: R56.2, U40.6 (MAIN_TERM)
unnamed: R57.2, U41.6 (MAIN_TERM)
unnamed: R58.1, U46.1 (Anode)
unnamed: R59.1, U47.1 (Anode)
unnamed: R60.1, U48.1 (Anode)
unnamed: R61.1, U49.1 (Anode)
unnamed: R62.2, U46.6 (MAIN_TERM)
unnamed: R63.2, U47.6 (MAIN_TERM)
unnamed: R64.2, U48.6 (MAIN_TERM)
unnamed: R65.2, U49.6 (MAIN_TERM)
unnamed: R66.1, U54.1 (Anode)
unnamed: R67.1, U55.1 (Anode)
unnamed: R68.1, U56.1 (Anode)
unnamed: R69.1, U57.1 (Anode)
unnamed: R70.2, U54.6 (MAIN_TERM)
unnamed: R71.2, U55.6 (MAIN_TERM)
unnamed: R72.2, U56.6 (MAIN_TERM)
unnamed: R73.2, U57.6 (MAIN_TERM)
unnamed: R74.1, U62.1 (Anode)
unnamed: R75.1, U63.1 (Anode)
unnamed: R76.1, U64.1 (Anode)
unnamed: R77.1, U65.1 (Anode)
unnamed: R78.2, U62.6 (MAIN_TERM)
unnamed: R79.2, U63.6 (MAIN_TERM)
unnamed: R80.2, U64.6 (MAIN_TERM)
unnamed: R81.2, U65.6 (MAIN_TERM)
unnamed: U38.4 (MAIN_TERM), U42.3 (G)
unnamed: U39.4 (MAIN_TERM), U43.3 (G)
unnamed: U40.4 (MAIN_TERM), U44.3 (G)
unnamed: U41.4 (MAIN_TERM), U45.3 (G)
unnamed: U46.4 (MAIN_TERM), U50.3 (G)
unnamed: U47.4 (MAIN_TERM), U51.3 (G)
unnamed: U48.4 (MAIN_TERM), U52.3 (G)
unnamed: U49.4 (MAIN_TERM), U53.3 (G)
unnamed: U54.4 (MAIN_TERM), U58.3 (G)
unnamed: U55.4 (MAIN_TERM), U59.3 (G)
unnamed: U56.4 (MAIN_TERM), U60.3 (G)
unnamed: U57.4 (MAIN_TERM), U61.3 (G)
unnamed: U62.4 (MAIN_TERM), U66.3 (G)
unnamed: U63.4 (MAIN_TERM), U67.3 (G)
unnamed: U64.4 (MAIN_TERM), U68.3 (G)
unnamed: U65.4 (MAIN_TERM), U69.3 (G)

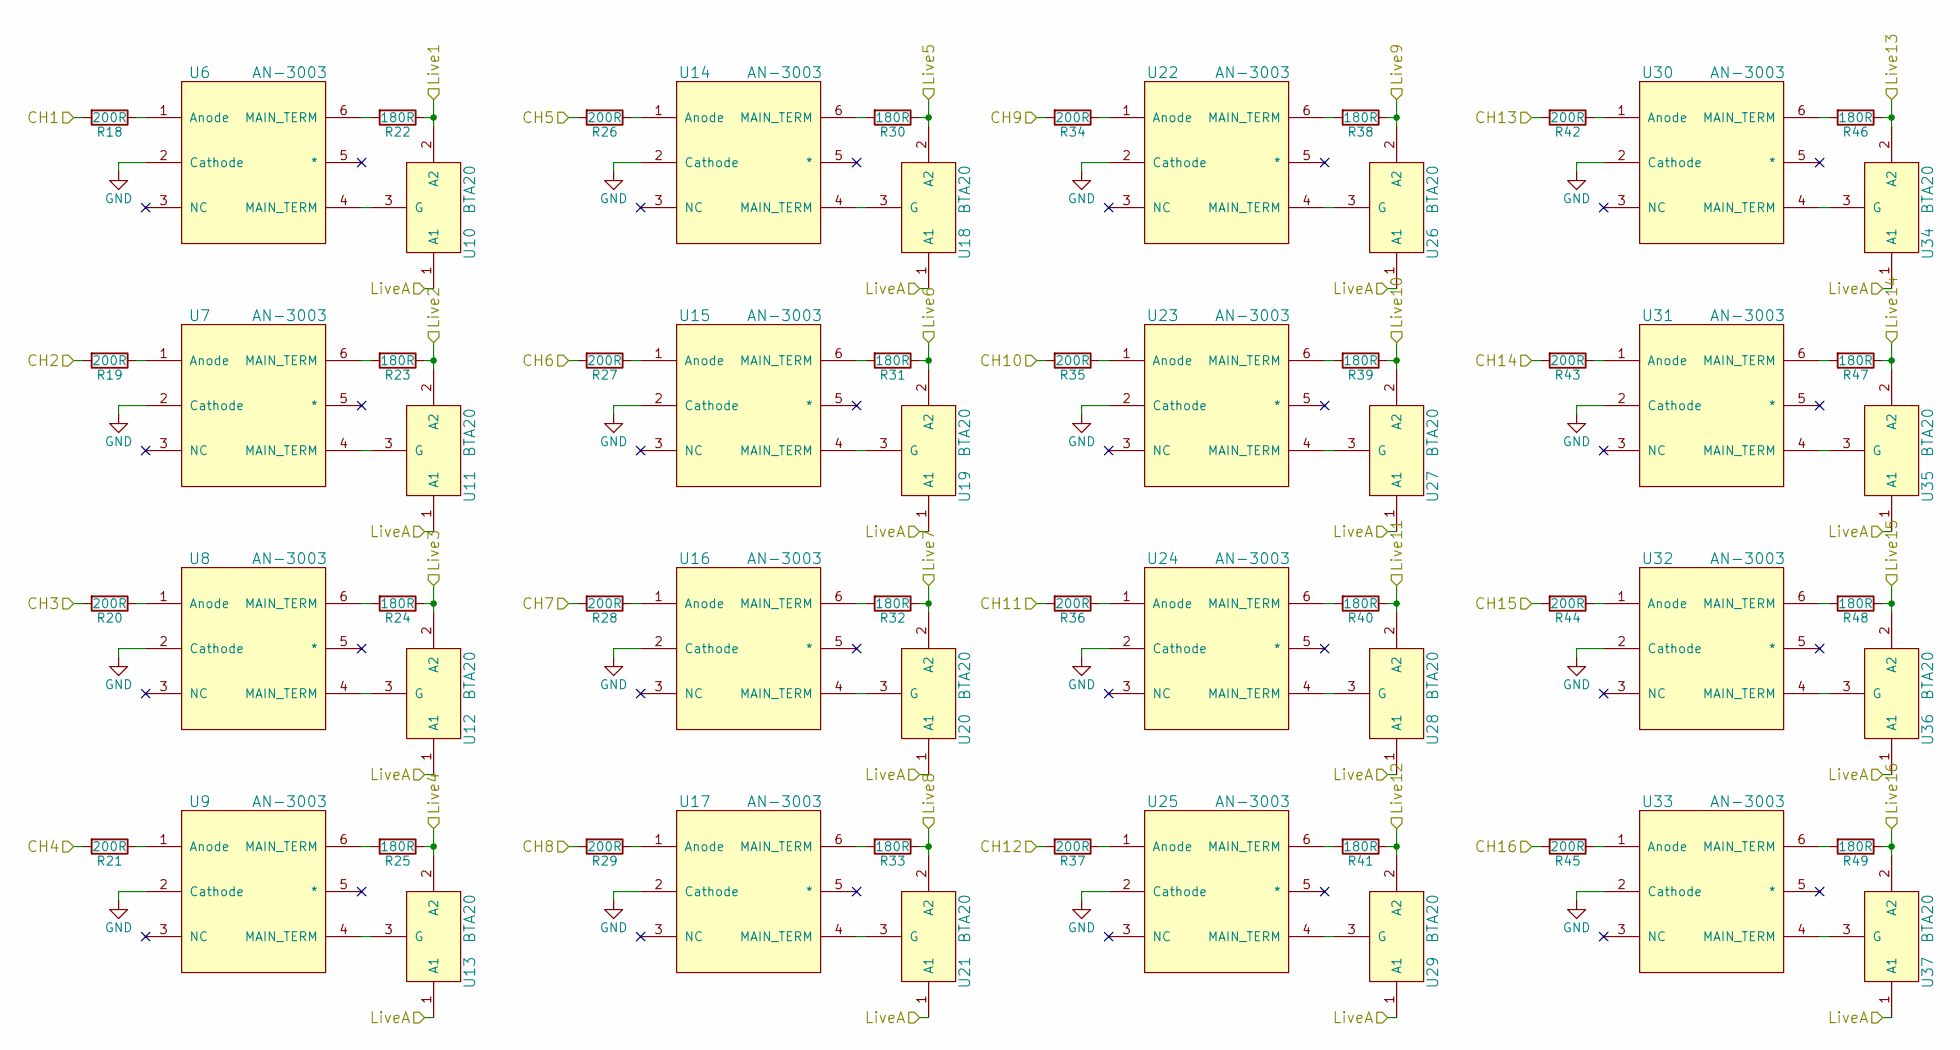
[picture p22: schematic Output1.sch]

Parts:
R18, R19, R20, R21, R26, R27, R28, R29, R34, R35, R36, R37, R42, R43, R44, R45: 200R; R_0603
R22, R23, R24, R25, R30, R31, R32, R33, R38, R39, R40, R41, R46, R47, R48, R49: 180R; R_0603
U6, U7, U8, U9, U14, U15, U16, U17, U22, U23, U24, U25, U30, U31, U32, U33: AN-3003; DIP-6_W7.62mm_LongPads
U10, U11, U12, U13, U18, U19, U20, U21, U26, U27, U28, U29, U34, U35, U36, U37: BTA20; TO-220

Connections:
/Output1/CH1: R18.2; also elsewhere on the board
/Output1/CH2: R19.2; also elsewhere on the board
/Output1/CH3: R20.2; also elsewhere on the board
/Output1/CH4: R21.2; also elsewhere on the board
/Output1/CH5: R26.2; also elsewhere on the board
/Output1/CH6: R27.2; also elsewhere on the board
/Output1/CH7: R28.2; also elsewhere on the board
/Output1/CH8: R29.2; also elsewhere on the board
/Output1/CH9: R34.2; also elsewhere on the board
/Output1/CH10: R35.2; also elsewhere on the board
/Output1/CH11: R36.2; also elsewhere on the board
/Output1/CH12: R37.2; also elsewhere on the board
/Output1/CH13: R42.2; also elsewhere on the board
/Output1/CH14: R43.2; also elsewhere on the board
/Output1/CH15: R44.2; also elsewhere on the board
/Output1/CH16: R45.2; also elsewhere on the board
/Output1/Live1: R22.1, U10.2 (A2); also elsewhere on the board
/Output1/Live2: R23.1, U11.2 (A2); also elsewhere on the board
/Output1/Live3: R24.1, U12.2 (A2); also elsewhere on the board
/Output1/Live4: R25.1, U13.2 (A2); also elsewhere on the board
/Output1/Live5: R30.1, U18.2 (A2); also elsewhere on the board
/Output1/Live6: R31.1, U19.2 (A2); also elsewhere on the board
/Output1/Live7: R32.1, U20.2 (A2); also elsewhere on the board
/Output1/Live8: R33.1, U21.2 (A2); also elsewhere on the board
/Output1/Live9: R38.1, U26.2 (A2); also elsewhere on the board
/Output1/Live10: R39.1, U27.2 (A2); also elsewhere on the board
/Output1/Live11: R40.1, U28.2 (A2); also elsewhere on the board
/Output1/Live12: R41.1, U29.2 (A2); also elsewhere on the board
/Output1/Live13: R46.1, U34.2 (A2); also elsewhere on the board
/Output1/Live14: R47.1, U35.2 (A2); also elsewhere on the board
/Output1/Live15: R48.1, U36.2 (A2); also elsewhere on the board
/Output1/Live16: R49.1, U37.2 (A2); also elsewhere on the board
/Output1/LiveA: U10.1 (A1), U11.1 (A1), U12.1 (A1), U13.1 (A1), U18.1 (A1), U19.1 (A1), U20.1 (A1), U21.1 (A1), U26.1 (A1), U27.1 (A1), U28.1 (A1), U29.1 (A1), U34.1 (A1), U35.1 (A1), U36.1 (A1), U37.1 (A1); also elsewhere on the board
unnamed: R18.1, U6.1 (Anode)
unnamed: R19.1, U7.1 (Anode)
unnamed: R20.1, U8.1 (Anode)
unnamed: R21.1, U9.1 (Anode)
unnamed: R22.2, U6.6 (MAIN_TERM)
unnamed: R23.2, U7.6 (MAIN_TERM)
unnamed: R24.2, U8.6 (MAIN_TERM)
unnamed: R25.2, U9.6 (MAIN_TERM)
unnamed: R26.1, U14.1 (Anode)
unnamed: R27.1, U15.1 (Anode)
unnamed: R28.1, U16.1 (Anode)
unnamed: R29.1, U17.1 (Anode)
unnamed: R30.2, U14.6 (MAIN_TERM)
unnamed: R31.2, U15.6 (MAIN_TERM)
unnamed: R32.2, U16.6 (MAIN_TERM)
unnamed: R33.2, U17.6 (MAIN_TERM)
unnamed: R34.1, U22.1 (Anode)
unnamed: R35.1, U23.1 (Anode)
unnamed: R36.1, U24.1 (Anode)
unnamed: R37.1, U25.1 (Anode)
unnamed: R38.2, U22.6 (MAIN_TERM)
unnamed: R39.2, U23.6 (MAIN_TERM)
unnamed: R40.2, U24.6 (MAIN_TERM)
unnamed: R41.2, U25.6 (MAIN_TERM)
unnamed: R42.1, U30.1 (Anode)
unnamed: R43.1, U31.1 (Anode)
unnamed: R44.1, U32.1 (Anode)
unnamed: R45.1, U33.1 (Anode)
unnamed: R46.2, U30.6 (MAIN_TERM)
unnamed: R47.2, U31.6 (MAIN_TERM)
unnamed: R48.2, U32.6 (MAIN_TERM)
unnamed: R49.2, U33.6 (MAIN_TERM)
unnamed: U6.4 (MAIN_TERM), U10.3 (G)
unnamed: U7.4 (MAIN_TERM), U11.3 (G)
unnamed: U8.4 (MAIN_TERM), U12.3 (G)
unnamed: U9.4 (MAIN_TERM), U13.3 (G)
unnamed: U14.4 (MAIN_TERM), U18.3 (G)
unnamed: U15.4 (MAIN_TERM), U19.3 (G)
unnamed: U16.4 (MAIN_TERM), U20.3 (G)
unnamed: U17.4 (MAIN_TERM), U21.3 (G)
unnamed: U22.4 (MAIN_TERM), U26.3 (G)
unnamed: U23.4 (MAIN_TERM), U27.3 (G)
unnamed: U24.4 (MAIN_TERM), U28.3 (G)
unnamed: U25.4 (MAIN_TERM), U29.3 (G)
unnamed: U30.4 (MAIN_TERM), U34.3 (G)
unnamed: U31.4 (MAIN_TERM), U35.3 (G)
unnamed: U32.4 (MAIN_TERM), U36.3 (G)
unnamed: U33.4 (MAIN_TERM), U37.3 (G)

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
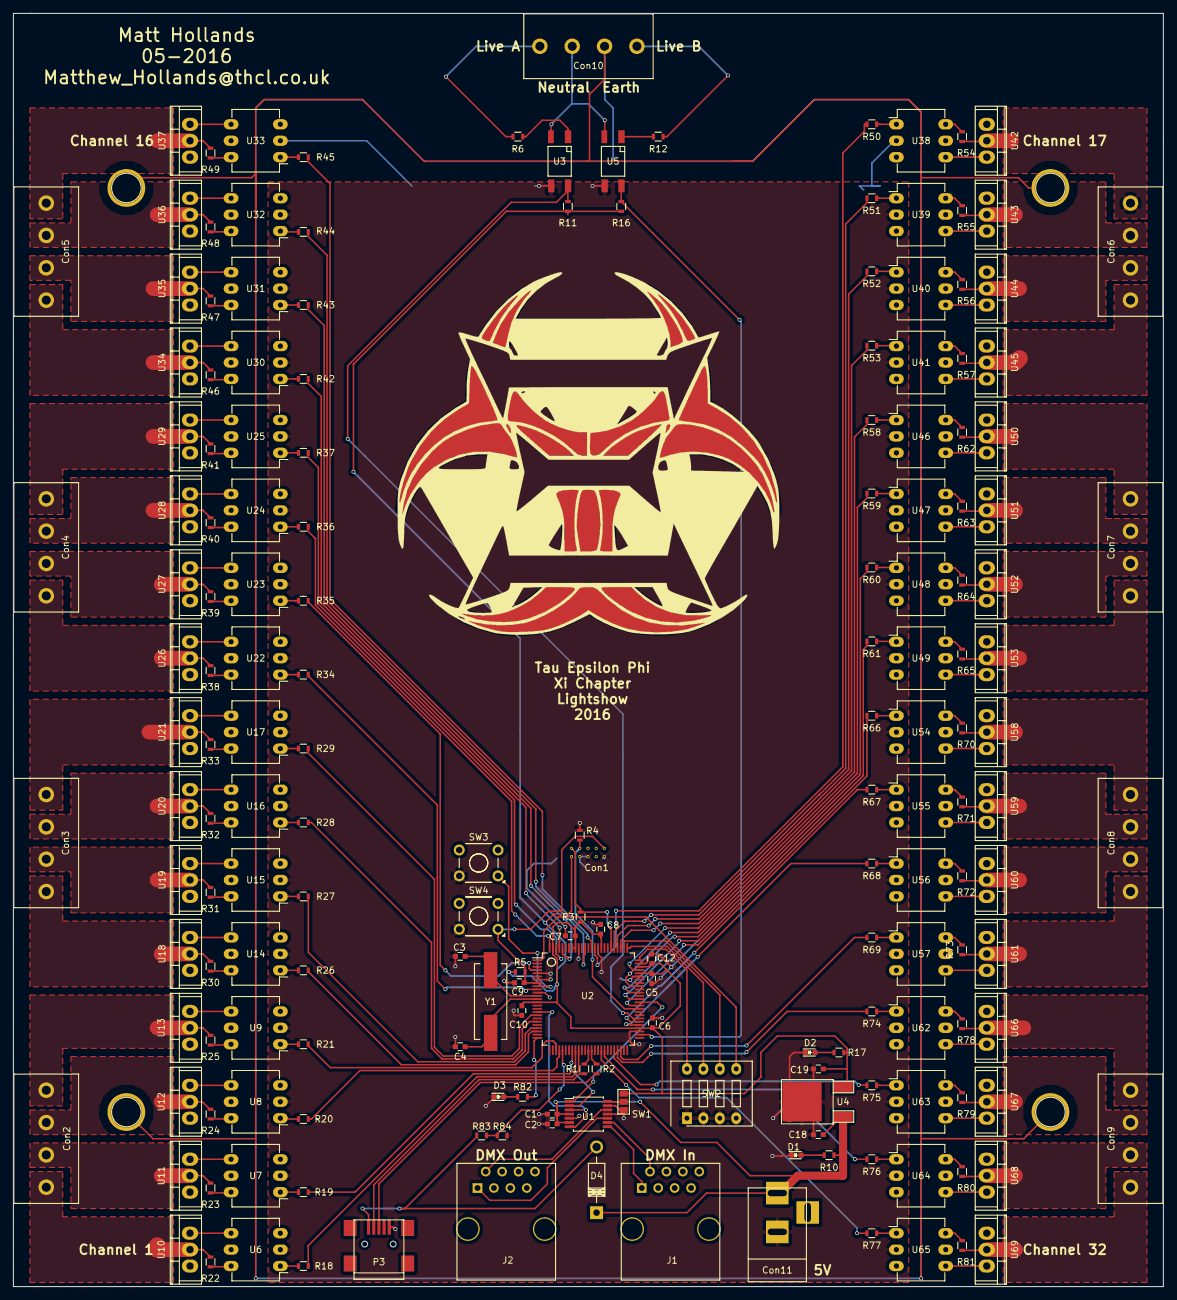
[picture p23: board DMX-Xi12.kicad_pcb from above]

Board: 2 copper layers, 177.8 x 196.8 mm, 183 parts (0 on the bottom side), 198 nets.

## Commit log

2016-01-30 started schematics for DMX-Xi12 slave board
    [DMX-Xi12.kicad_pcb, DMX-Xi12.sch]
2016-02-02 finished input stage and started work on processor stage
    [DMX-Xi12-Front-End.sch, DMX-Xi12-Processor.sch, DMX-Xi12.sch]
2016-02-06 added output stage
    [DMX-Xi12-Front-End.sch, DMX-Xi12-Processor.sch, DMX-Xi12.sch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]
2016-02-22 more schematic
    [DMX-Xi12-Processor.sch, DMX-Xi12.sch, Output1.sch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]
2016-02-22 changed processor to 3.3v and added programming
    [DMX-Xi12-Processor.sch, Power.sch]
2016-02-28 made dlaw changes etc
    [DMX-Xi12-Front-End.sch, DMX-Xi12-Processor.sch, DMX-Xi12.sch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]
2016-04-04 working on pcb
    [DMX-Xi12-Front-End.sch, DMX-Xi12-Processor.sch, DMX-Xi12.sch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]
2016-04-04 more work on board
    [DMX-Xi12.kicad_pcb, DMX-Xi12.sch, Output1.sch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]
2016-05-07 completed board. Schematic, is correct but some part values and numbers need updating! Do not trust the schematic yet
    [DMX-Xi12-BEFORE MOD.kicad_pcb, DMX-Xi12-Before-mess.kicad_pcb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]
2016-05-07 added PDF of final board layout
